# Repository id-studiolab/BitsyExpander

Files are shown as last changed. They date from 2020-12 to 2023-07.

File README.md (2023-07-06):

[][cc-by]

# Bitsy Expander

An expansion board adding support for the Grove solderless connector system, a WiFi radio, and LiPo battery charging circuitry to Adafruit ItsyBitsy Development Boards.

Compatible with all ItsyBitsy boards, the Bitsy Expander is available in two distinct flavors. The silkscreens on each flavor are specifically tailored to either the [ItsyBitsy M4 Express](https://www.adafruit.com/product/3800) or the [ItsyBitsy RP2040](https://www.adafruit.com/product/4888).

**Jump ahead:**

* [Bitsy Expander M4](#bitsy-expander-m4)
* [Bitsy Expander RP2040](#bitsy-expander-rp2040)
* [General Information](#general-information)
* [FAQ](#faq)
* [Version History](#version-history)

## Bitsy Expander M4

### Preview

<p align="center">
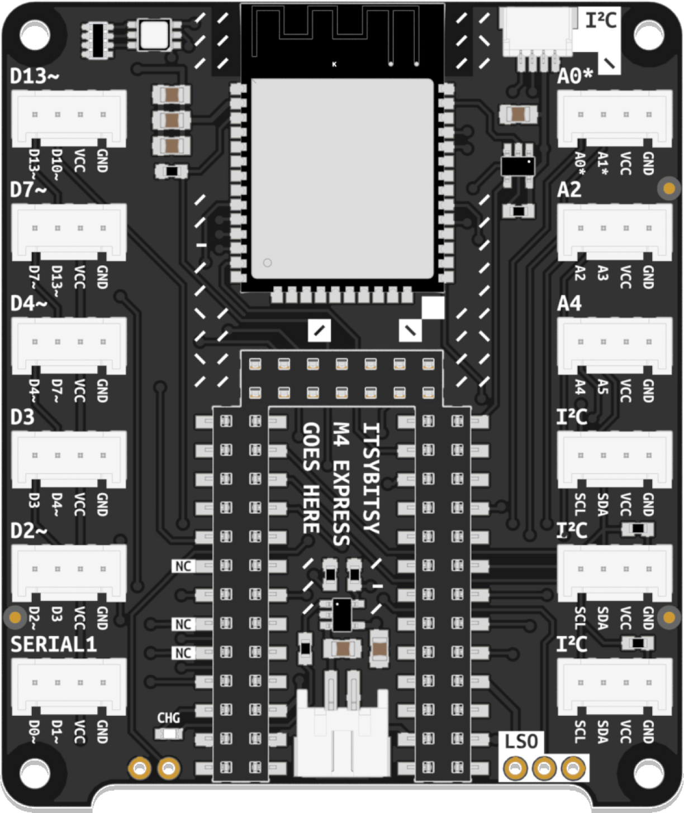
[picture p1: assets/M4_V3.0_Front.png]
Bitsy Expander M4 Front
  
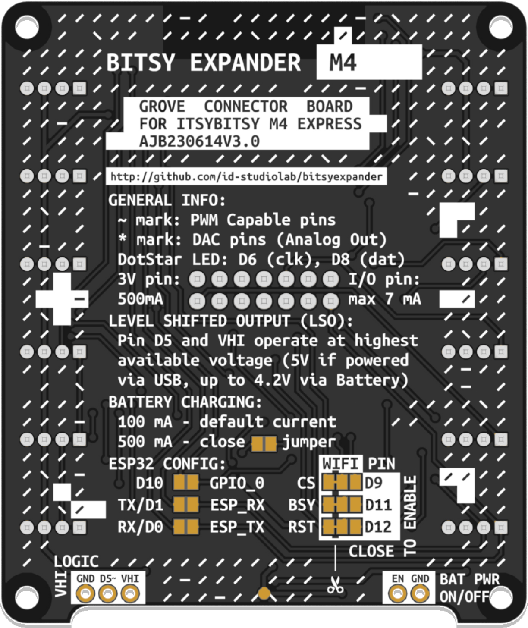
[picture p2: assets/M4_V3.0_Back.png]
Bitsy Expander M4 Back
  
</p>

### Features

* 12 Grove Headers
  - 5 Digital Headers with overlapping (shingled) pins: D2, D3, D4, D7, D13
  - 1 Digital Header with exclusive pins: SERIAL1
  - 3 Analog Headers with exclusive pins: A0, A2, A4
  - 3 I²C Headers
* ESP32-WROOM Co-Processor for WiFi and BLE
* 1 JST SH 4-pin connector for Qwiic and STEMMA QT components (I²C)
* 1 JST PH 2-pin connector for 3.7V LiPo Batteries (chargeable via ItsyBitsy's USB port)
* 1 Logic-shifted output (allows driving components requiring 5V logic while powered via USB)

> NOTE: In shingled pin headers, each header's second pin is shared with the first pin in the header above it. Therefore, using one disables the other. For instance, using pins D3 and D4 in the  D3-labeled header disallows the use of D4 in the D4-labeled header.

### Pinout Diagrams

Additional resources and pinout diagrams are available **[here](M4_info.md)**.

## Bitsy Expander RP2040

### Preview

<p align="center">
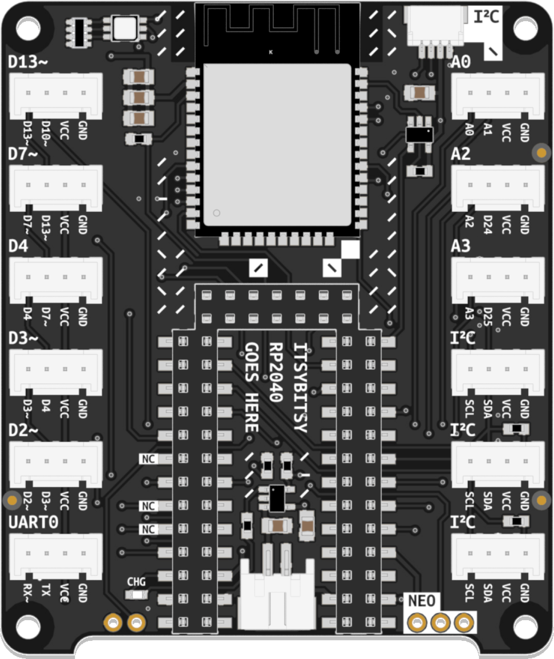
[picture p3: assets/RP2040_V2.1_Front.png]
Bitsy Expander RP2040 Front
  
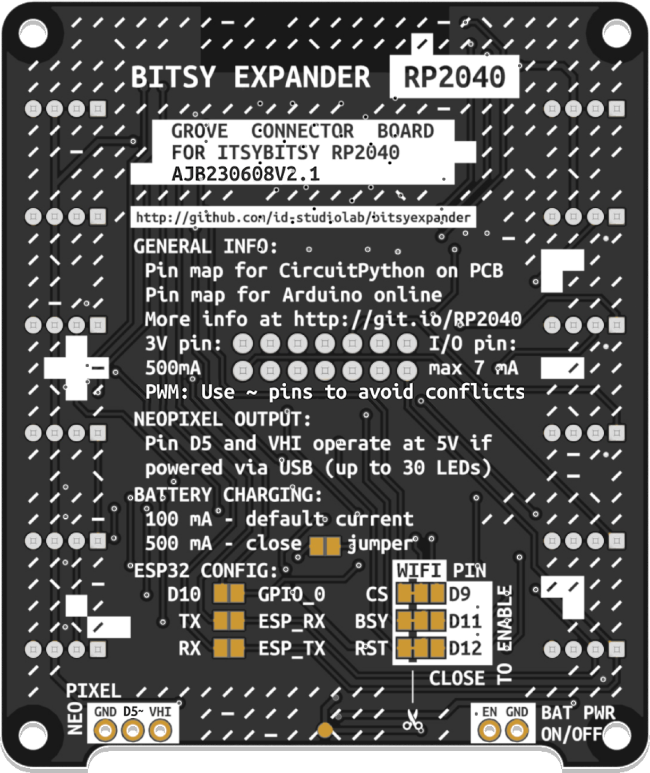
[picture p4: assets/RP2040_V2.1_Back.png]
Bitsy Expander RP2040 Back
  
</p>

### Features

* 12 Grove Headers
  - 5 Digital Headers with overlapping (shingled) pins: D2, D3, D4, D7, D13
  - 1 Digital Header with exclusive pins: UART0
  - 3 Analog Headers with exclusive pins: A0, A2, A3 (A2 and A3 contain digital pins for their second pins)
  - 3 I²C Headers
* ESP32-WROOM Co-Processor for WiFi and BLE
* 1 JST SH 4-pin connector for Qwiic and STEMMA QT components (I²C)
* 1 JST PH 2-pin connector for 3.7V LiPo Batteries (chargeable via ItsyBitsy's USB port)
* 1 Logic-shifted output (allows driving components requiring 5V logic while powered via USB)

> NOTE: In shingled pin headers, each header's second pin is shared with the first pin in the header above it. Therefore, using one disables the other. For instance, using pins D3 and D4 in the  D3-labeled header disallows the use of D4 in the D4-labeled header.

### Pinout Diagrams

Additional resources and pinout diagrams are available **[here](RP2040_info.md)**.

## General Information

### WiFi and BLE

The Bitsy Expander uses an ESP32 WROOM module to provide WiFi functionality to the microcontroller using [Adafruit's fork](https://github.com/adafruit/nina-fw) of the Arduino NINA-W102 firmware. In CircuitPython, this library also allows for the use of Bluetooth Low Energy (BLE).

To use the module with Circuitpython, use the [esp32spi](https://docs.circuitpython.org/projects/esp32spi/en/latest/) library. For Arduino, [Adafruit's forked WiFiNINA](https://github.com/adafruit/WiFiNINA/) library is required.

The ESP32 module is connected as follows:

| ESP32 Pin | ItsyBitsy Pin |
| --- | --- |
| Chip Select (CS) | D9 |
| Busy (BSY) | D11 |
| Reset (RST) | D12 |
| SPI Clock (SCK)  | SCK |
| SPI MISO | MISO |
| SPI MOSI | MOSI |

### Solder Jumpers

The underside of the Bitsy Expander features a number of solder jumpers:

#### WIFI PIN:

These pins are used to connect the ItsyBitsy board to the ESP32 module on the Expander. If WiFi functionality is not needed but additional digital pins are required, these jumpers can be used to disable the WiFi module and make additional pins available in the double-row header on the upper side of the board. The traces between the middle and left pads must be severed before soldering a jumper in place between the middle and the right pads to do so.

#### ESP32 CONFIG:

These solder jumpers are normally open. If the ESP32 module requires a firmware update, these jumpers may be used to enable the ItsyBitsy to serve as a programming interface for the ESP32 module. Refer to [Adafruit's excellent tutorial](https://learn.adafruit.com/upgrading-esp32-firmware) on flashing firmware onto the ESP32.

#### BATTERY CHARGING:

The default battery charging current is 100mA. A faster, 500mA charging mode is available for batteries that support it. It can be enabled by closing the solder jumper.

## FAQ

#### How do I recognize which Bitsy Expander I have?

<p align="center">
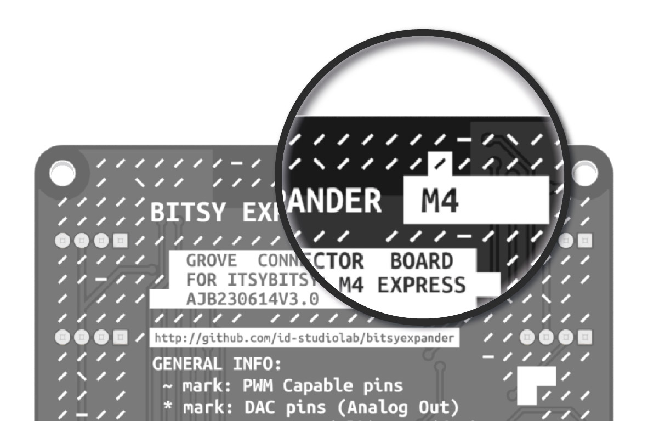
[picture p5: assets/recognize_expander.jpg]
Identify Expander Type
  
</p>

The easiest way to identify which Bitsy Expander flavor you own is checking the label on the back of the board. **RP2040** or **M4** stated on the label indicates the flavor of your Expander. Older M4 Expanders have an **empty label** (and are also recognizable by the lack of an I²C header at the top). 

#### How do I recognize which ItsyBitsy Development Board I am using?

<p align="center" style="display: flex; justify-content: center;">
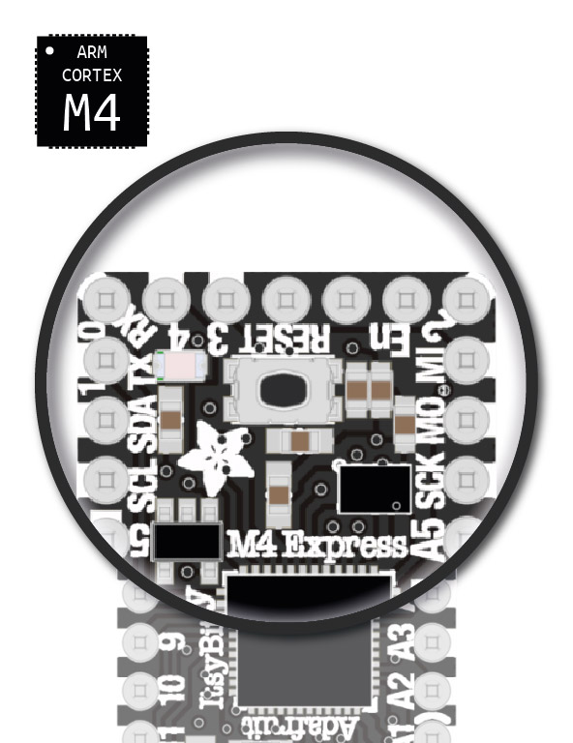
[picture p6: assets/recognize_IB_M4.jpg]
Identify ItsyBitsy M4 Express
  
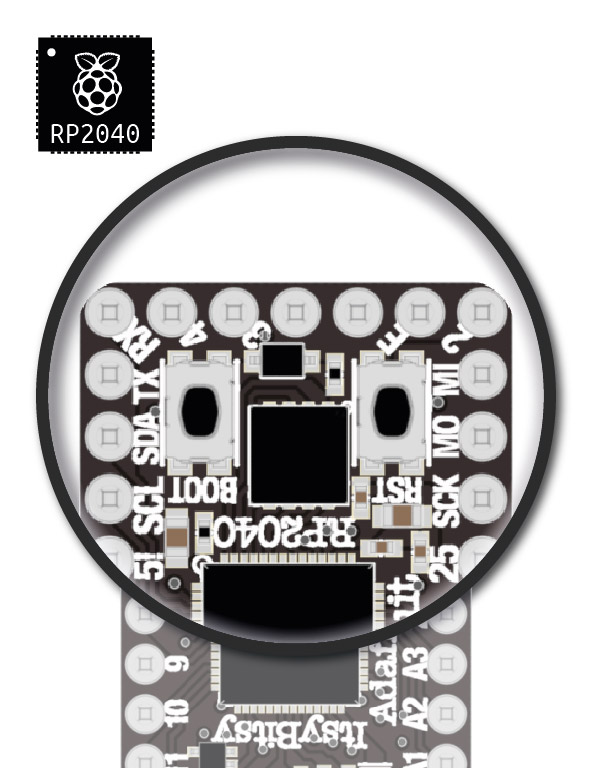
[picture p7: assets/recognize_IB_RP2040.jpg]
Identify ItsyBitsy RP2040
  
</p>

The **ItsyBitsy M4 Express** features **one (RESET) button**. (So do most other ItsyBitsy Development boards, so always verify with the silkscreen.)
The **ItsyBitsy RP2040** features **two (BOOT, RESET) buttons**.

#### Will any ItsyBitsy-type microcontroller work with any Bitsy Expander?

In principle, yes. The silkscreen on either flavor is specifically designed for either the [ItsyBitsy M4 Express](https://www.adafruit.com/product/3800) or the [ItsyBitsy RP2040](https://www.adafruit.com/product/4888), respectively. Pinouts differ only slightly between ItsyBitsy Development boards, however. The M4 Expander, for instance, has also been used successfully with the [ItsyBitsy M0 Express](https://www.adafruit.com/product/3727) in the past. This repository includes a number of pinout diagrams for different use-cases.

## Version History

| Version | Comment | Known Issues | Flavors |
| --- | --- | --- | --- |
| **1.0** | Initial version | Using pin D13 to drive the ESP Chip Select (CS) causes interference between the microcontroller's internal LED and the pull-up resistor | M4 Express |
| 1.1 | – Uses pin D9 instead of D13 to drive the ESP Chip Select to prevent interference  <br />– Adds a test point to the expander's underside for VBAT accessibility | Only two Grove headers provide direct access to Analog pins of used with RP2040 | M4 Express, RP2040 |
| **2.0** | – Adds a top-edge JST SH 4-pin connector for Qwiic and STEMMA QT compatibility  <br />– Repositions pin A3 for better RP2040 analog pin access<br />– Adds "NC" (not connected) labels to double-row header pins that are not normally broken out | Tilde (~) marks inaccurately represent freely configurable PWM pins on RP2040. *Note: all pins support PWM, subject to certain limitations.* | RP2040 |
| 2.1 | Silkscreen update to accurately depict a selection of freely configurable PWM pins on RP2040, preventing configuration conflicts among them | | RP2040 |
| **3.0** | – Reinstates original pin layout (identical to V1) for sequential analog pin placement on M4 Express <br />– Maintains JST SH-4 connector and VBAT test point inherited from previous versions | | M4 Express |

This is the sibling of the [Nano Expander](https://github.com/id-studiolab/NanoExpander), a Grove expansion board for [Arduino Nano 33 IoT](https://store.arduino.cc/products/arduino-nano-33-iot).

This work is licensed under a
[Creative Commons Attribution 4.0 International License][cc-by].

[][cc-by]

[cc-by]: http://creativecommons.org/licenses/by/4.0/
[cc-by-image]: https://i.creativecommons.org/l/by/4.0/88x31.png
[cc-by-shield]: https://img.shields.io/badge/License-CC%20BY%204.0-lightgrey.svg

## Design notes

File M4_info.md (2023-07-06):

# Bitsy Expander M4 Pinout Diagrams
The ItsyBitsy M4 Express is a powerful and versatile development board powered by a 32-bit Cortex M4 microcontroller running at 120 MHz. It features two 12-bit DACs, seven 12-bit ADCs, and plenty PWM-capable outputs. 

This page provides an overview of the pins made available via the Grove headers on the Bitsy Expander M4.

**For detailed information on the pinout of the ItsyBitsy M4 Express, refer to Adafruit's documentation:**  

[Adafruit ItsyBitsy M4 Express](https://learn.adafruit.com/introducing-adafruit-itsybitsy-m4)

**Jump ahead to pinout diagram:**

* [Pinout for Standard Usage](#standard-usage)
* [Original Bitsy Expander (Version 1.1)](#original-bitsy-expander-version-11)
* [Alternative Use with ItsyBitsy RP2040](#alternative-use-with-itsybitsy-rp2040)

## Standard Usage

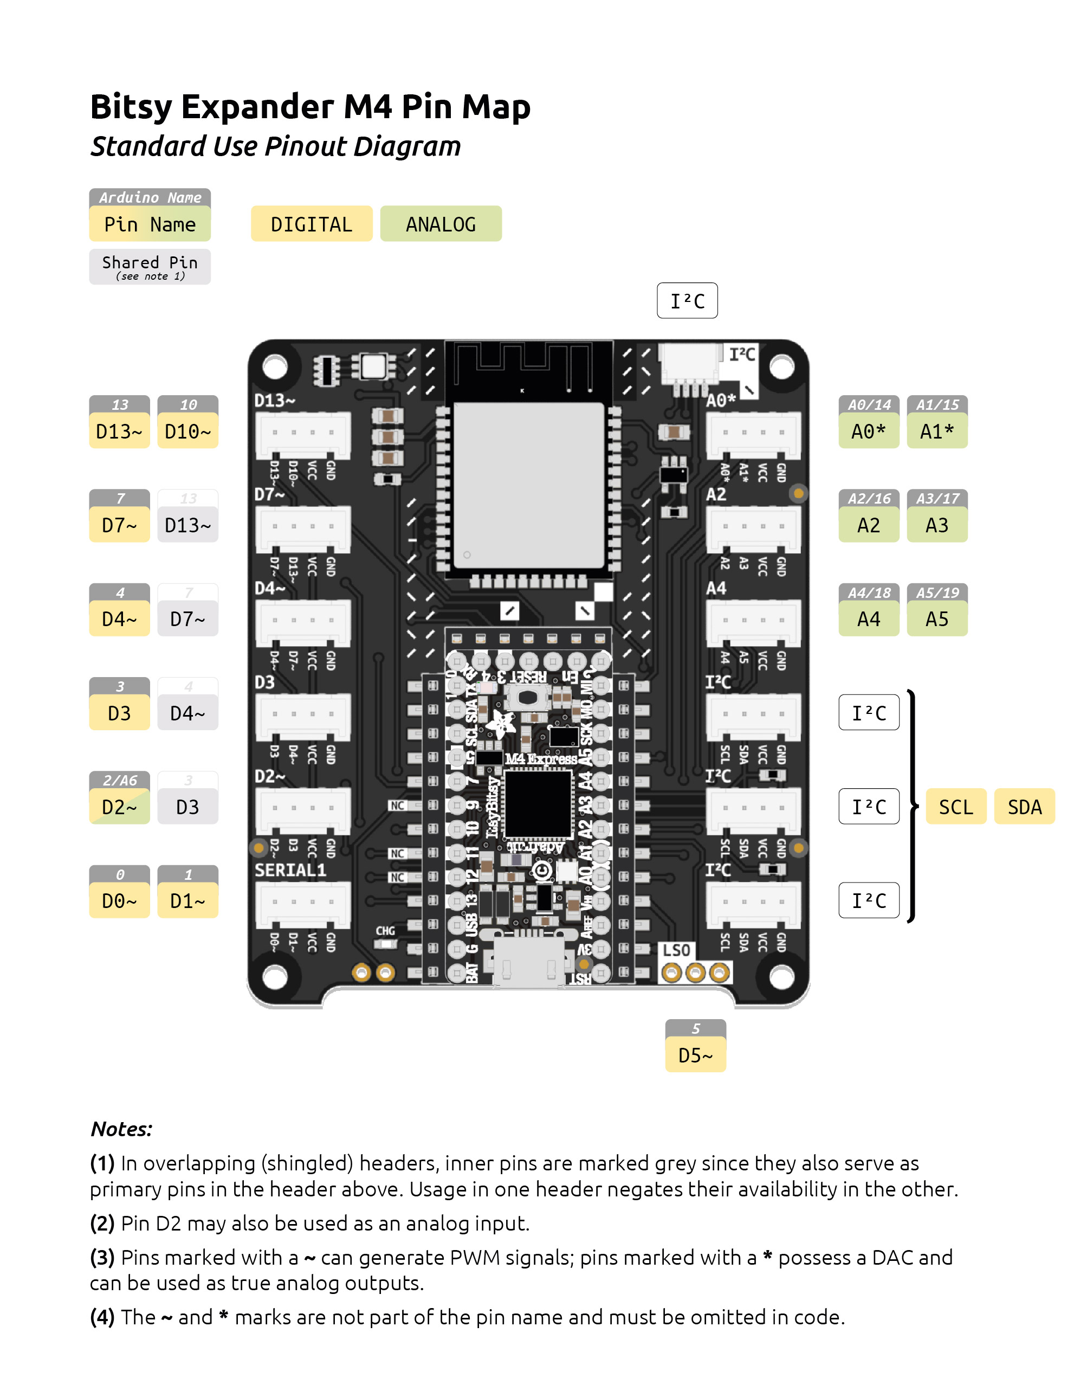
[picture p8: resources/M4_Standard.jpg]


## Original Bitsy Expander (Version 1.1)
The pinout of this version is identical to the version pictured above. The only major difference is the absence of the additional I²C header at the top of the board. This diagram serves as a visual reference for older boards still in circulation.

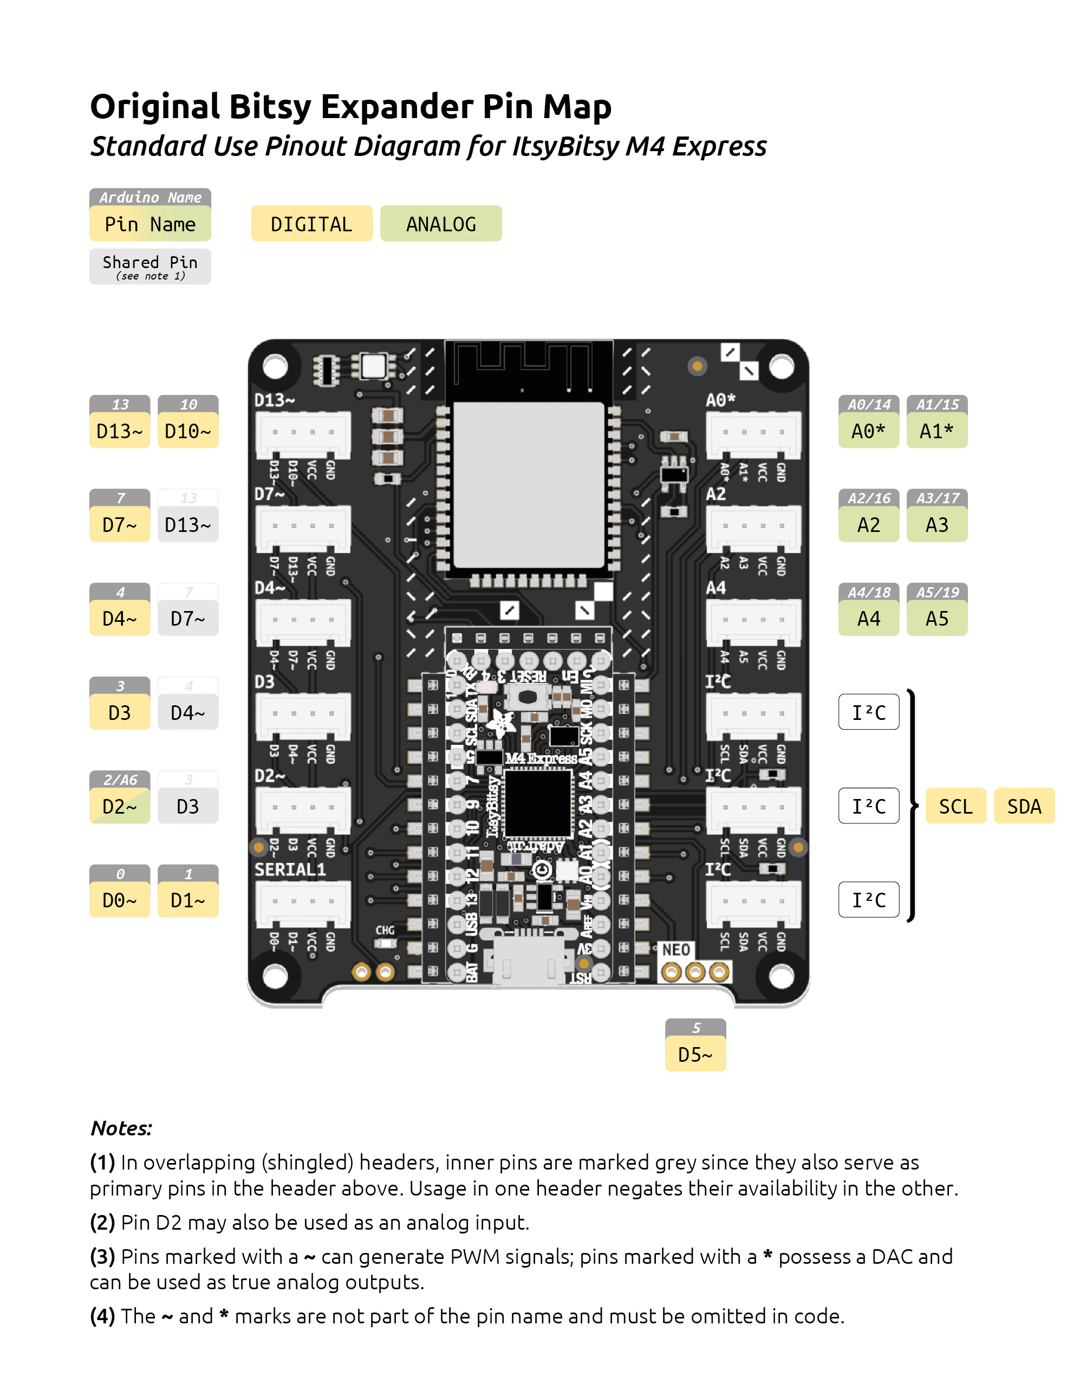
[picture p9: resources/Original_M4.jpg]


## Alternative Use with ItsyBitsy RP2040

Should you opt to use a Bitsy Expander M4 with an ItsyBitsy RP2040 development board, please refer to the pinout diagram below:

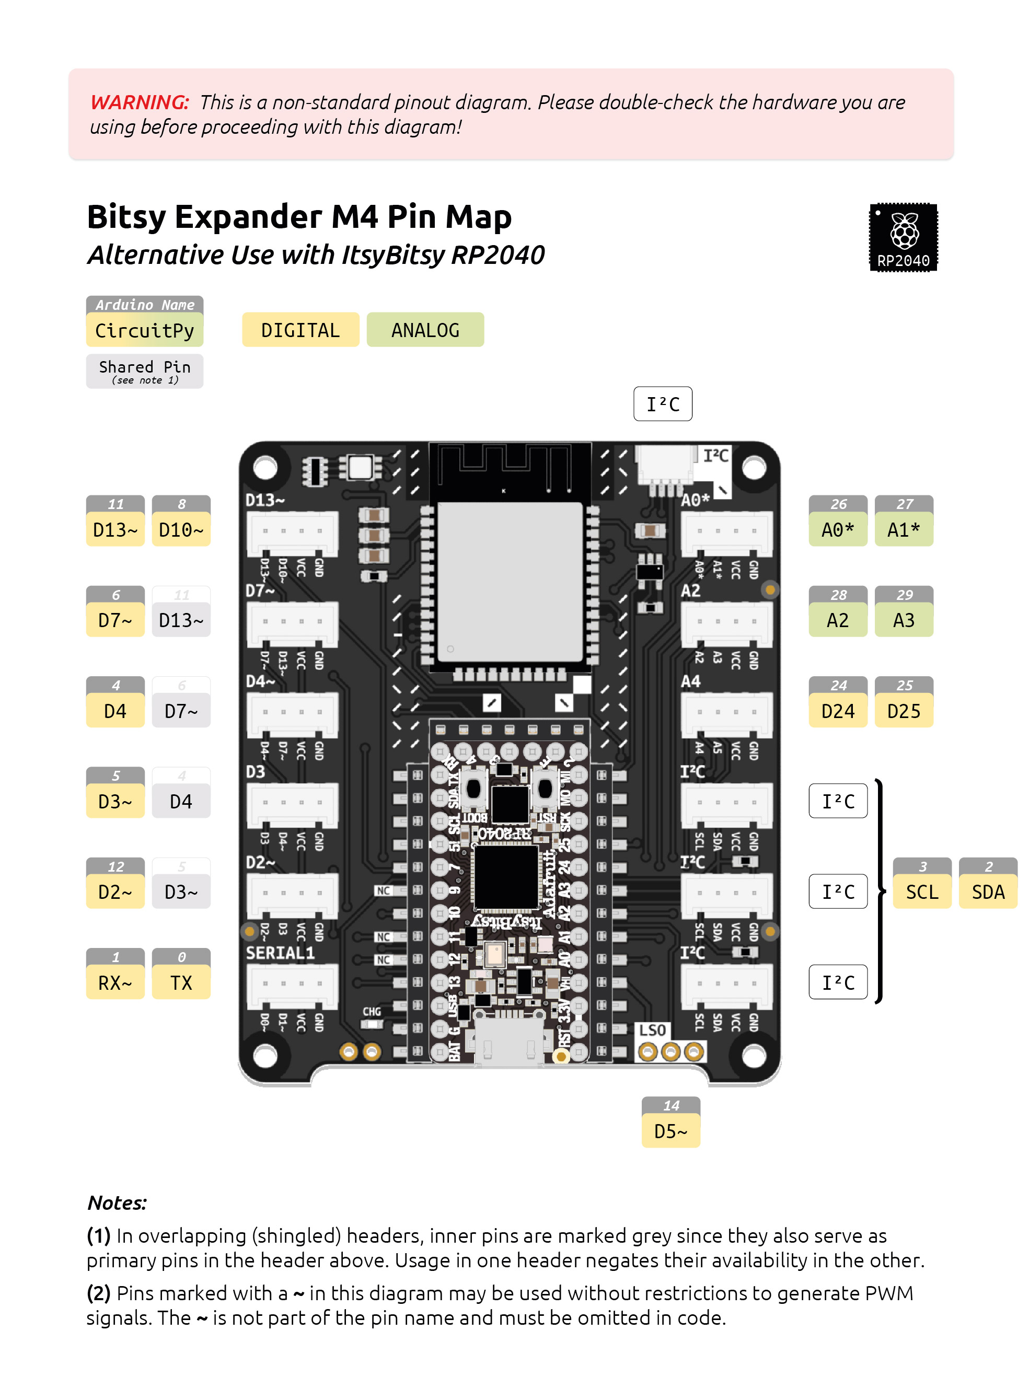
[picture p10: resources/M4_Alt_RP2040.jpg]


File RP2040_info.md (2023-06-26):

# Bitsy Expander RP2040 Pinout Diagrams
Unlike the ItsyBitsy M4, which includes two more analog pins (and two DACs), the RP2040 replaces these with two additional digital pins. The RP2040 affords greater flexibility in GPIO pin usage, but extra planning and research may be needed to fully leverage this advantage.

**For detailed information on the ItsyBitsy RP2040's pinout, refer to Adafruit's documentation:**  

[Adafruit ItsyBitsy RP2040](https://learn.adafruit.com/adafruit-itsybitsy-rp2040)

**Jump ahead to pinout diagram:**

* [Pinout for Standard Usage](#standard-usage)
* [Advanced PWM and PIO Reference](#advanced-pwm-and-pio-reference)
* [Pinout for use in Arduino IDE](#arduino-support)
* [Alternative Use with ItsyBitsy M4 Express](#alternative-use-with-itsybitsy-m4-express)

## Standard Usage

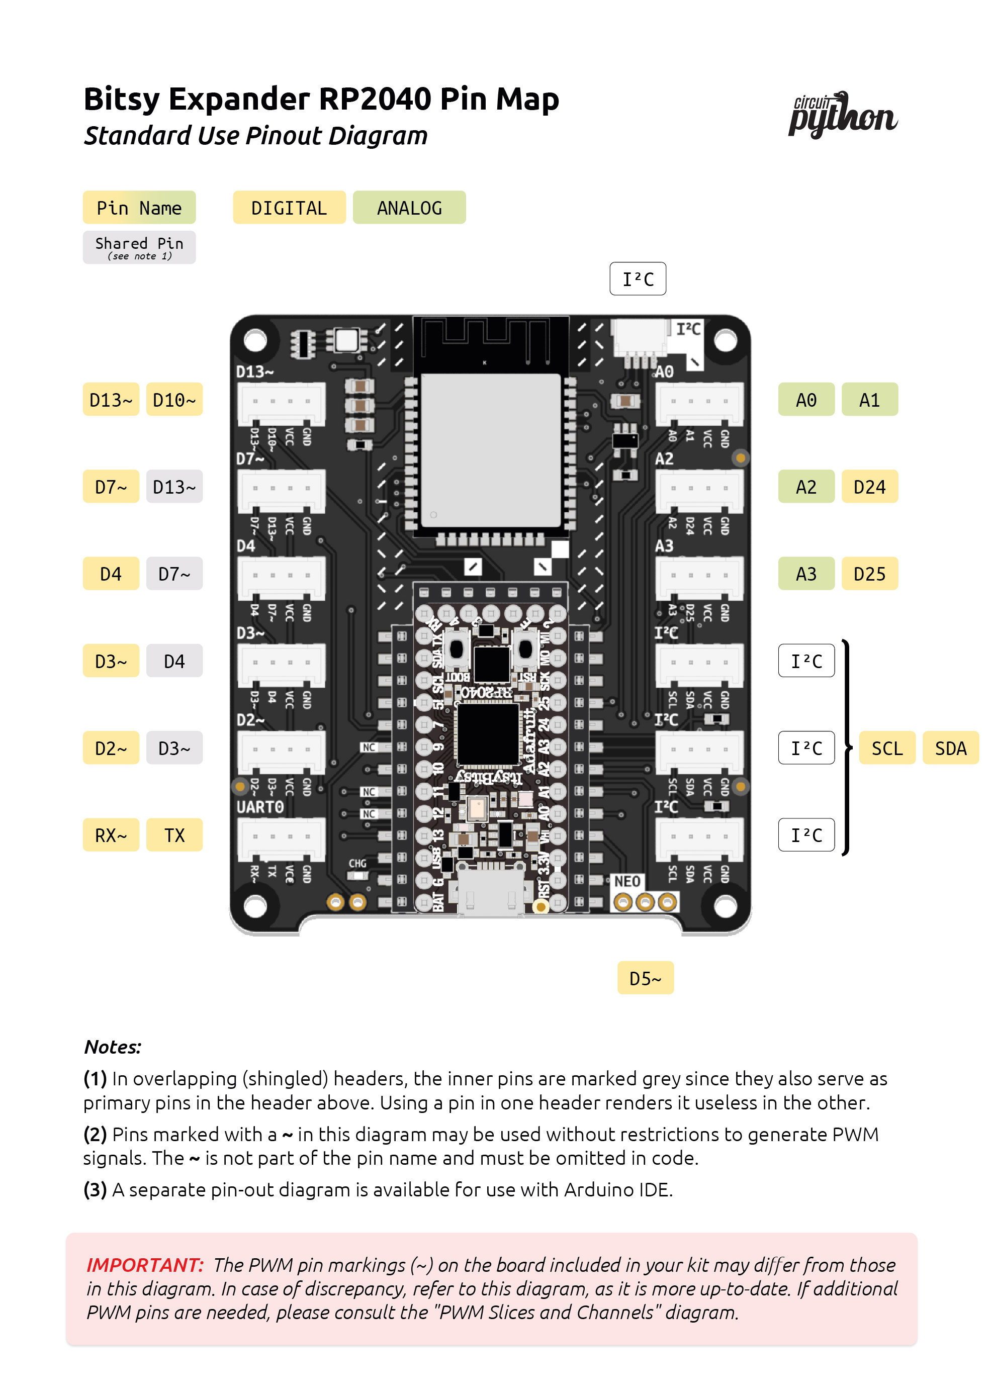
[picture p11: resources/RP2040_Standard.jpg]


## Advanced PWM and PIO Reference
The RP2040 is a highly capable microcontroller that features flexible hardware support for Pulse Width Modulation (PWM) and Programmable I/O (PIO). With 8 available PWM slices, each offering 2 channels, and 2 PIO  blocks with 4 state machines each, developers can control a variety of digital peripherals and create custom digital interfaces.

However, this versatility necessitates careful planning. While every IO can generate PWM signals, restrictions apply to the simultaneous use of specific pins. (e.g., pins sharing a common PWM slice must adopt identical frequency settings.) These constraints allow simultaneous PWM use of all pins for many standard use-cases. For scenarios requiring custom settings, the silkscreen displays marks (~) for a group of pins that can be freely configured without causing conflicts. For more advanced needs, the diagram below serves as a reference. Please refer to Note 3 in the diagram for more information.

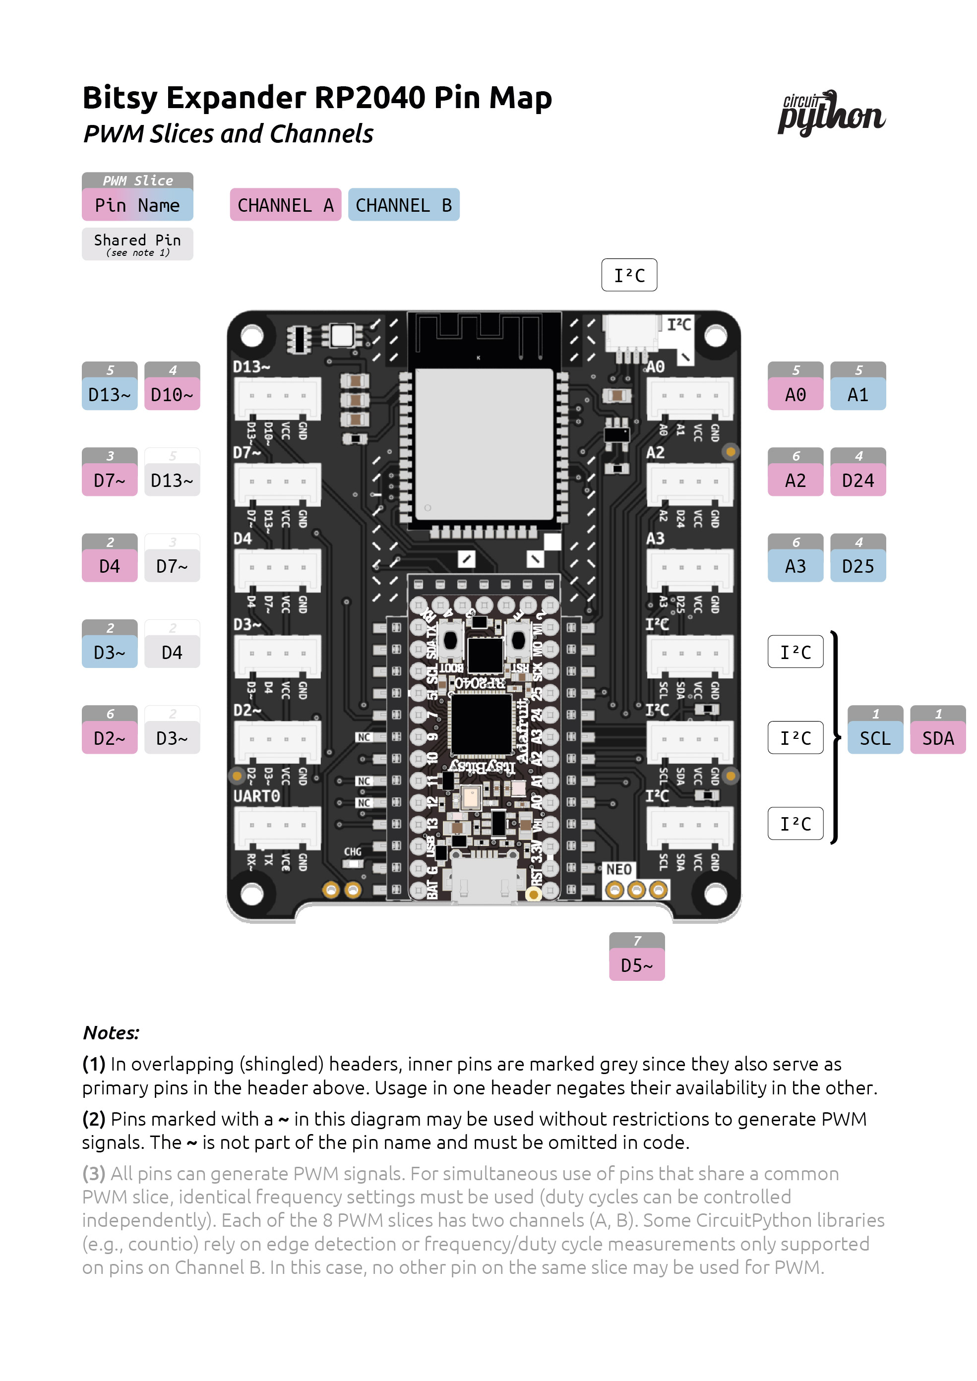
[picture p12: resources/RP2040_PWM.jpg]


## Arduino Support
The pin markings on both the BitsyExpander RP2040 and the ItsyBitsy RP2040 itself are exclusively applicable for use with [CircuitPython](https://circuitpython.org/board/adafruit_itsybitsy_rp2040/). To program the board using [Arduino](https://learn.adafruit.com/adafruit-itsybitsy-rp2040/arduino-ide-setup), use the pin map provided here.

**Relevant links:**  
[Arduino IDE set-up for ItsyBitsy RP2040](https://learn.adafruit.com/adafruit-itsybitsy-rp2040/arduino-ide-setup)  
[Earlephilhower's Pi Pico Arduino Core](https://github.com/earlephilhower/arduino-pico/#arduino-pico)  

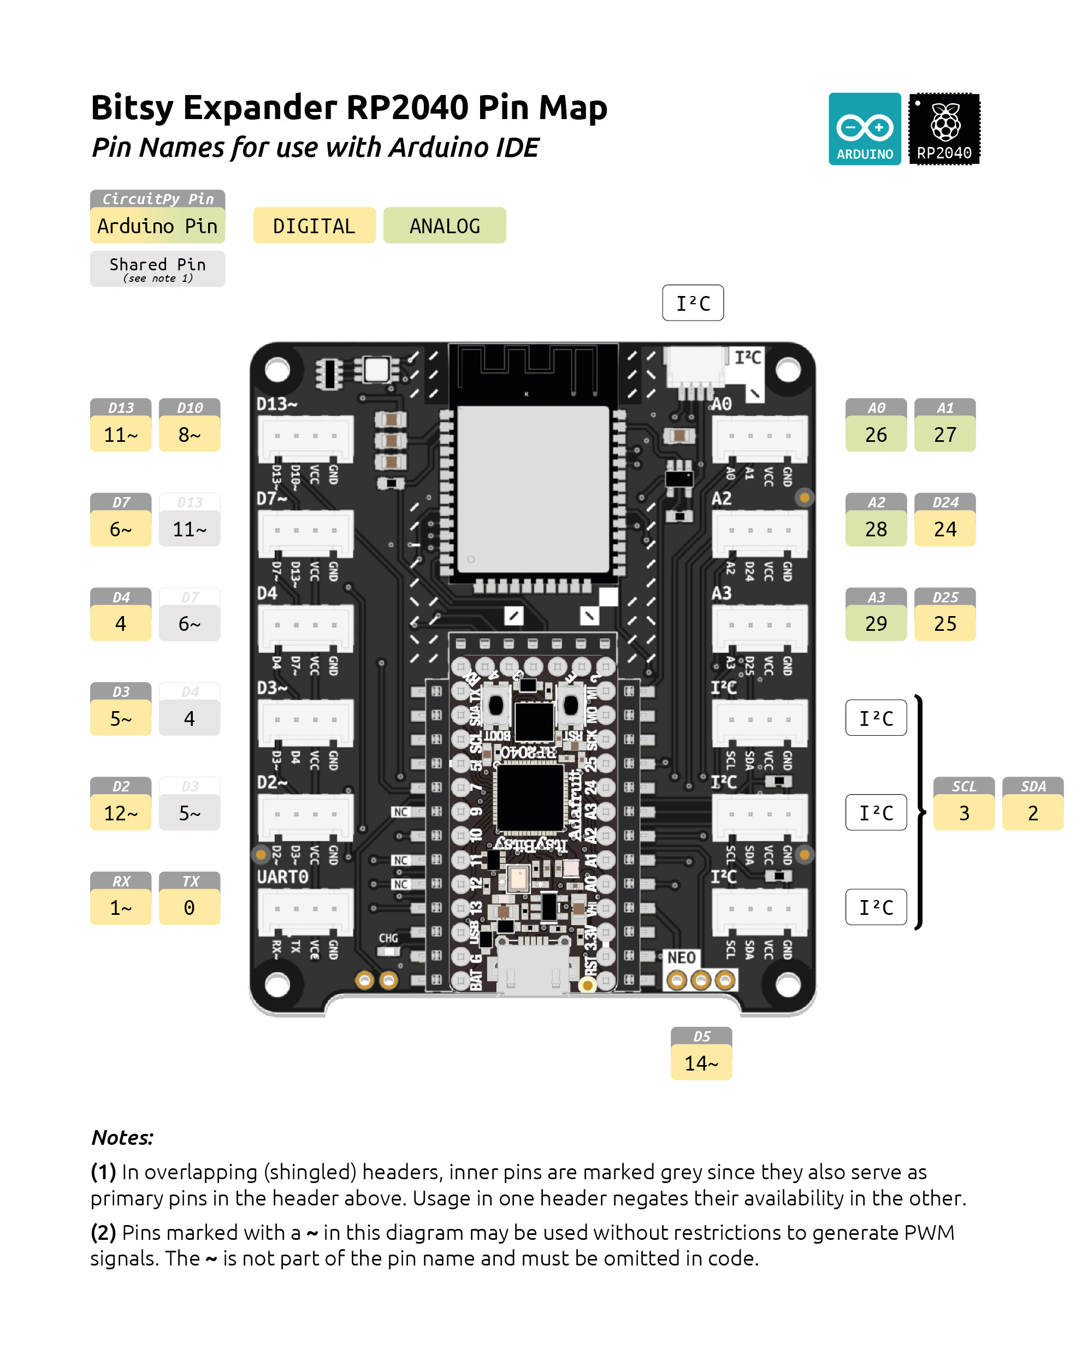
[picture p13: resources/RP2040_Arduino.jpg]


## Alternative Use with ItsyBitsy M4 Express

Should you opt to use a Bitsy Expander RP2040 with an ItsyBitsy M4 Express development board, please refer to the pinout diagram below:

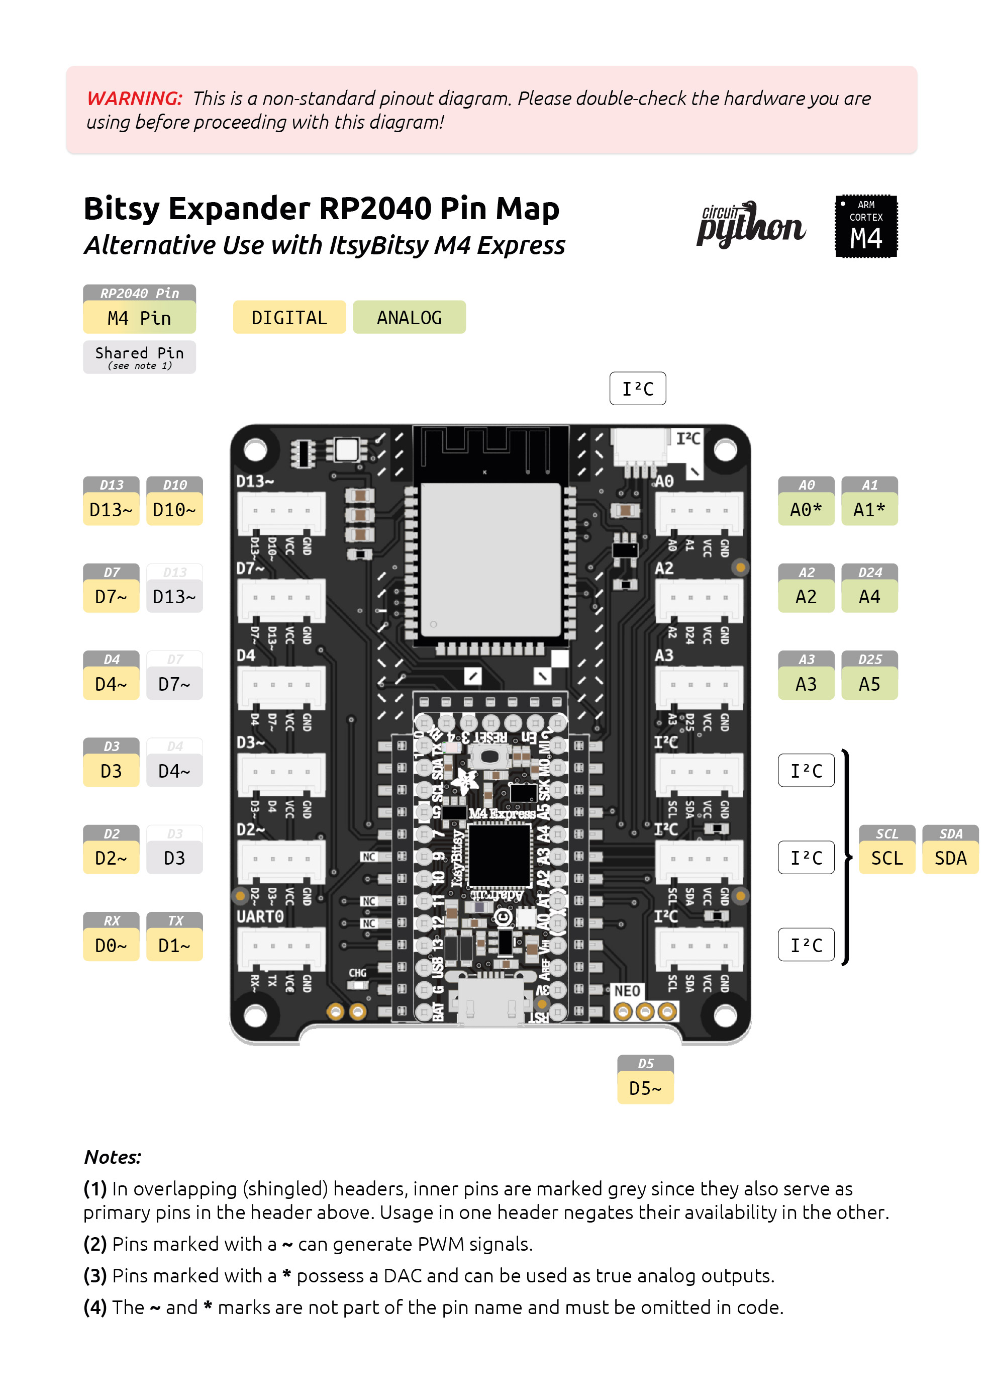
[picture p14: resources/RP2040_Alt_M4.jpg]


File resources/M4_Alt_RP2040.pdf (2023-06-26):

## Alternative Use with ItsyBitsy RP2040

## Bitsy Expander M4 Pin Map

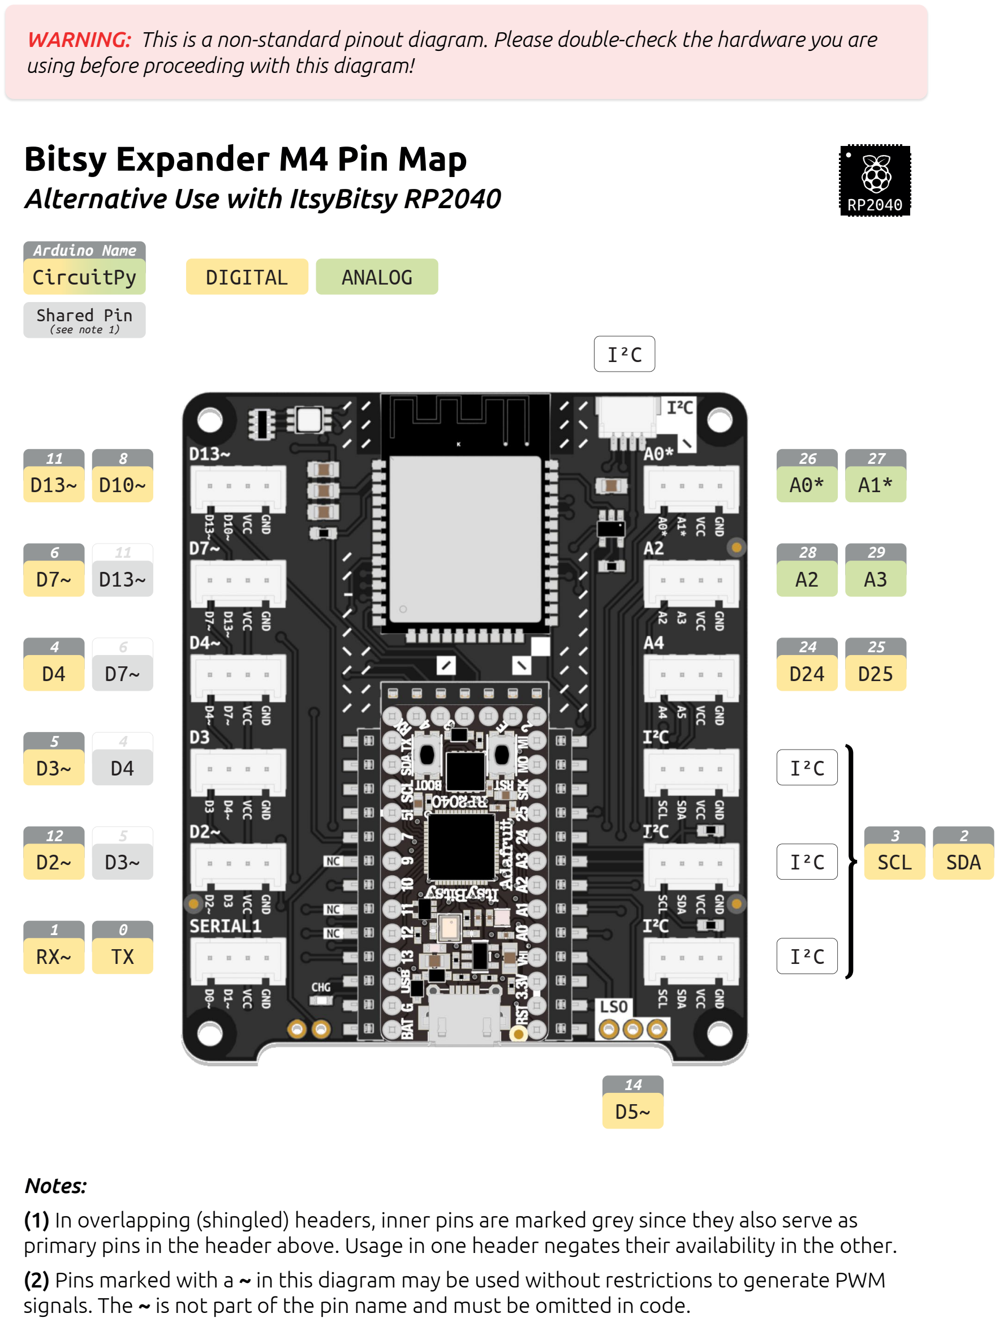
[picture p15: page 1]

D10~

8
D13~

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
D13~

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
I²C | SDA
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
RP2040

CircuitPy | DIGITAL | ANALOG

Arduino Name

Notes:
(1) In overlapping (shingled) headers, inner pins are marked grey since they also serve as primary pins in the header above. Usage in one header negates their availability in the other.
(2) Pins marked with a ~ in this diagram may be used without restrictions to generate PWM signals. The ~ is not part of the pin name and must be omitted in code.

WARNING: This is a non-standard pinout diagram. Please double-check the hardware you are using before proceeding with this diagram!

I²C

Shared Pin
(see note 1)

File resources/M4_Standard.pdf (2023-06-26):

## Bitsy Expander M4 Pin Map

## Standard Use Pinout Diagram

I²C

I²C | SCL | SDA

I²C

D10~

10
D13~

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
2⁄A6

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
D13~

13
D7~

7

A1*

A1⁄15
A0*

A0⁄14

A5

A5⁄19
A4

A4⁄18

A3

A3⁄17
A2

A2⁄16

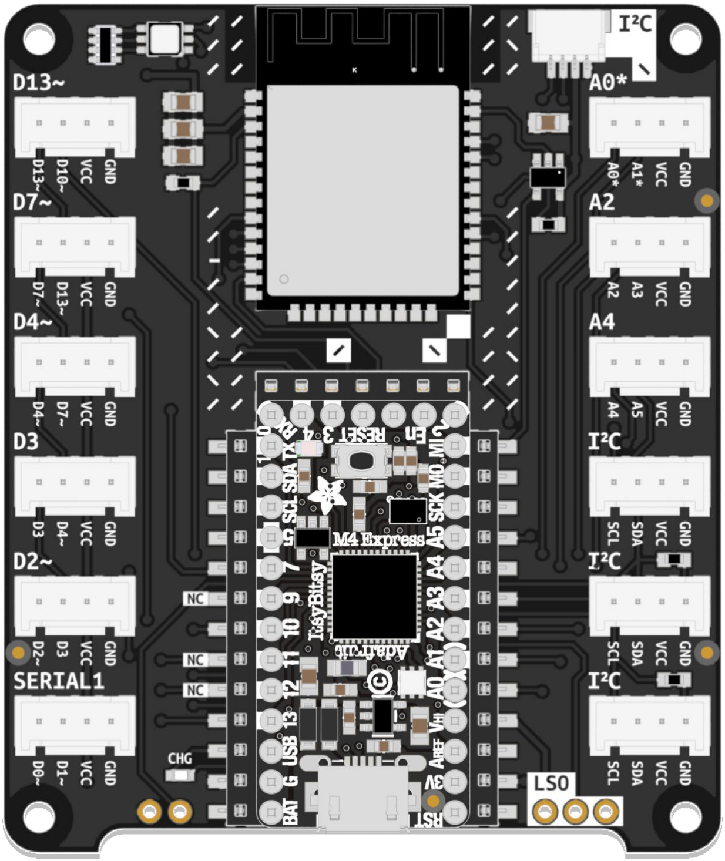
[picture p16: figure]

D5~

5

Pin Name

Arduino Name
DIGITAL ANALOG

Notes:
(1) In overlapping (shingled) headers, inner pins are marked grey since they also serve as primary pins in the header above. Usage in one header negates their availability in the other.
(2) Pin D2 may also be used as an analog input.
(3) Pins marked with a ~ can generate PWM signals; pins marked with a * possess a DAC and can be used as true analog outputs.
(4) The ~ and * marks are not part of the pin name and must be omitted in code.

I²C

Shared Pin
(see note 1)

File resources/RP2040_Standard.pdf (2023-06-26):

D13~ D10~

RX~ | TX
D2~ | D3~
D3~ | D4
D4 | D7~

D7~ D13~

A0 A1

I²C

I²C | SCL | SDA

I²C

I²C

A3 | D25
A2 | D24

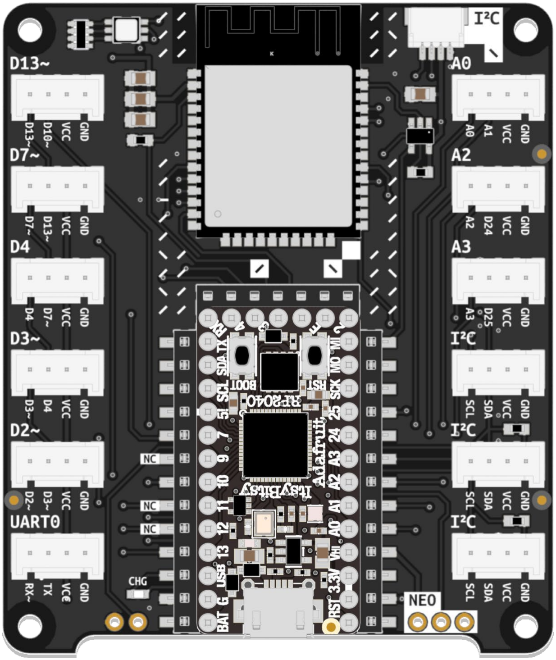
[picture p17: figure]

D5~

## Bitsy Expander RP2040 Pin Map

## Standard Use Pinout Diagram

Pin Name | DIGITAL | ANALOG

Notes:
(1) In overlapping (shingled) headers, the inner pins are marked grey since they also serve as primary pins in the header above. Using a pin in one header renders it useless in the other.
(2) Pins marked with a ~ in this diagram may be used without restrictions to generate PWM signals. The ~ is not part of the pin name and must be omitted in code.
(3) A separate pin-out diagram is available for use with Arduino IDE.

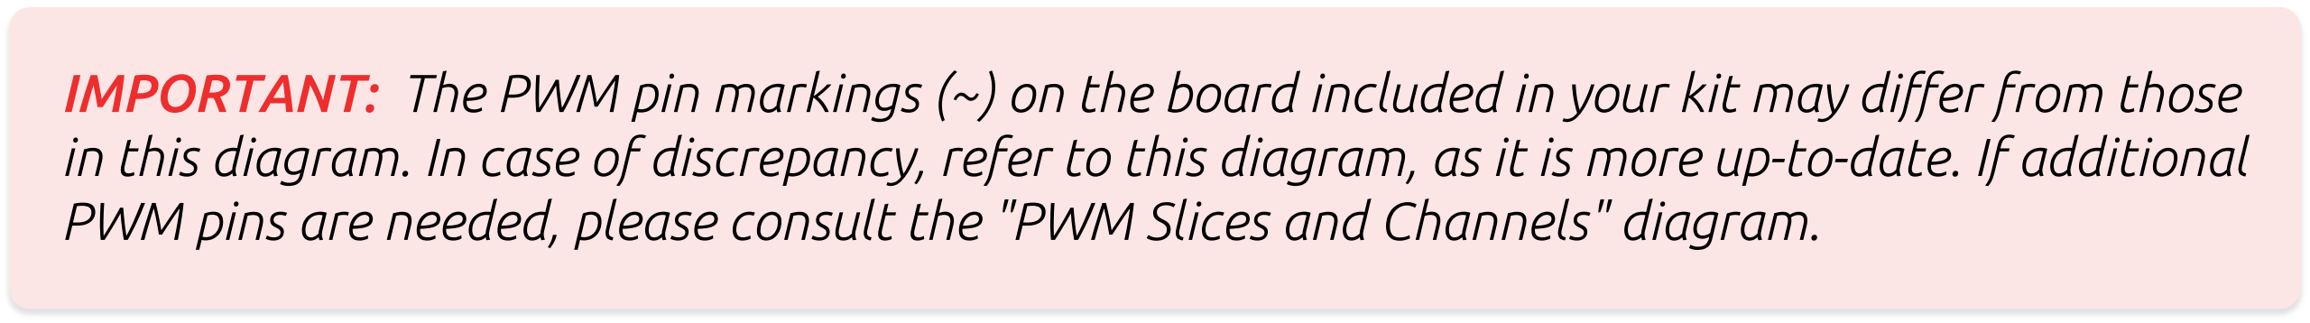
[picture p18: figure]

IMPORTANT: The PWM pin markings (~) on the board included in your kit may differ from those in this diagram. In case of discrepancy, refer to this diagram, as it is more up-to-date. If additional PWM pins are needed, please consult the "PWM Slices and Channels" diagram.

Shared Pin
(see note 1)

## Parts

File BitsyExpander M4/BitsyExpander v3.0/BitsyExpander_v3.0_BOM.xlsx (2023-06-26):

Designator | Manufacturer Part Number or Seeed SKU | Supplier | Qty | Value | Package | Link | Data sheet | Remarks
C1,C2,C3,C4,C5 | 302010158 | Seeed OPL | 5 | 10 µF | C0805 | https://statics3.seeedstudio.com/fusion/opl/datasheet/302010158.pdf
C6 | 302010165 | Seeed OPL | 1 | 0.1 µF | C0805 | https://statics3.seeedstudio.com/fusion/opl/datasheet/302010165.pdf
CON1 | SM04B-SRSS-TB(LF)(SN) | LCSC | 1 | 1x4 Pin | JST SH 4 Pin | https://lcsc.com/product-detail/Wire-To-Board-Wire-To-Wire-Connector_JST-Sales-America-SM04B-SRSS-TB-LF-SN_C160404.html | https://datasheet.lcsc.com/lcsc/1811151533_JST-Sales-America-SM04B-SRSS-TB-LF-SN_C160404.pdf | If possible to source, use black version: https://www.adafruit.com/product/4208
CON2 | S2B-PH-SM4-TB(LF)(SN) | LCSC | 1 | 1x2 Pin | JST PH 2 Pin | https://lcsc.com/product-detail/Wire-To-Board-Wire-To-Wire-Connector_JST-Sales-America-S2B-PH-SM4-TB-LF-SN_C295747.html | https://datasheet.lcsc.com/lcsc/2102031704_JST-Sales-America-S2B-PH-SM4-TB-LF-SN_C295747.pdf | If possible to source, use black version: https://www.adafruit.com/product/1769
CON3, CON4, CON5, CON6, CON7, CON8, CON9, CON10, CON11, CON12, CON13, CON14 | 320110033 | Seeed OPL | 12 | Seeed Grove Female Header | 4 Pin SMD | https://statics3.seeedstudio.com/fusion/opl/datasheet/320110033.pdf
CON15 | A2541HWV-2X7P | ShenZen OPL | 1 | 2x7 Pin | 2.54mm Pitch | https://file.elecfans.com/web1/M00/81/AC/o4YBAFw2vnKAaVFEACnRtF3lcuA967.pdf?filename=A2541_SERIES_CJT.pdf | https://www.cjt.com/Upload/A2541.pdf | 2.54mm Pitch 180° Female PTH 2x7 Pin Dual Row Header
CON16, CON17 | A2541HWV-S-2x13P | AliExpress | 2 | 2x13 Pin | 2.54mm Pitch | https://www.aliexpress.com/item/32798959899.html | https://www.cjt.com/Upload/A2541.pdf | 2.54mm Pitch 180° Female SMD 2x13 Pin Dual Row Header
LED1 | 304090042 | Seeed OPL | 1 | RED | 0603 | https://statics3.seeedstudio.com/fusion/opl/datasheet/304090042.pdf
LED2 | ASMT-YTD7-0AA02 | LCSC | 1 | ASMT-YTD7-0AA02 | 3528 | https://lcsc.com/product-detail/Light-Emitting-Diodes-LED_Broadcom-Limited-ASMT-YTD7-0AA02_C3018557.html | https://datasheet.lcsc.com/lcsc/2206171715_Broadcom-Limited-ASMT-YTD7-0AA02_C3018557.pdf
R1 | 301010298 | Seeed OPL | 1 | 1k | R0603 | https://statics3.seeedstudio.com/fusion/opl/datasheet/301010298.pdf
R2, R4, R5, R6, R7 | 301010299 | Seeed OPL | 5 | 10k | R0603 | https://statics3.seeedstudio.com/fusion/opl/datasheet/301010299.pdf
R3 | 0603WAF8252T5E | ShenZen OPL | 1 | 2.5k | R0603 | https://file.elecfans.com/web1/M00/8F/24/o4YBAFy-fqCABd01AAciZeje3jQ155.pdf
RN1 | WA06X222JTL | LCSC | 1 | 2.2K 4 Resistor Array | 4D03 | https://lcsc.com/product-detail/Resistor-Networks-Arrays_Walsin-Tech-Corp-WA06X222JTL_C168190.html
U1 | ESP32-WROOM-32E(8MB) | ShenZen OPL | 1 | ESP-WROOM-32 | ESP-WROOM-32 |  | https://www.espressif.com/sites/default/files/documentation/esp32-wroom-32e_esp32-wroom-32ue_datasheet_en.pdf
U2 | SN74AHC1G125DBVR | ShenZen OPL | 1 | 74AHC1G125 | SOT23-5L | https://file.elecfans.com/web1/M00/9F/43/pIYBAF1AqlCAeSb7ABGz_e2uUbE107.pdf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 | https://www.ti.com/lit/ds/symlink/sn74ahc1g125.pdf
U3 | MCP73831T-2ACI/OT | ShenZen OPL | 1 | MCP73831 | SOT23-5 | https://file.elecfans.com/web1/M00/9F/3E/pIYBAF1AlmqAaVGPAAzcNzr-I_c971.pdf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 | https://ww1.microchip.com/downloads/en/DeviceDoc/20001984g.pdf

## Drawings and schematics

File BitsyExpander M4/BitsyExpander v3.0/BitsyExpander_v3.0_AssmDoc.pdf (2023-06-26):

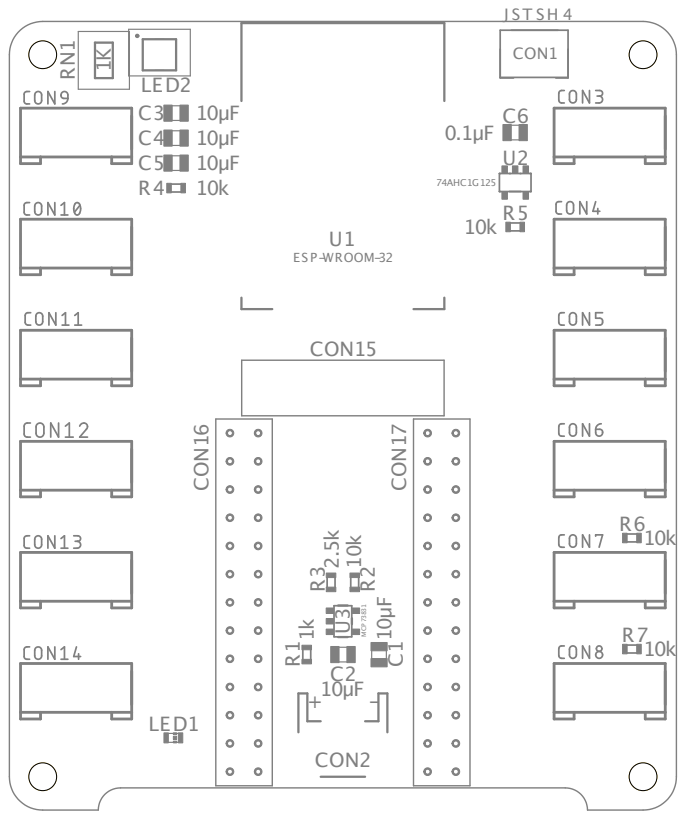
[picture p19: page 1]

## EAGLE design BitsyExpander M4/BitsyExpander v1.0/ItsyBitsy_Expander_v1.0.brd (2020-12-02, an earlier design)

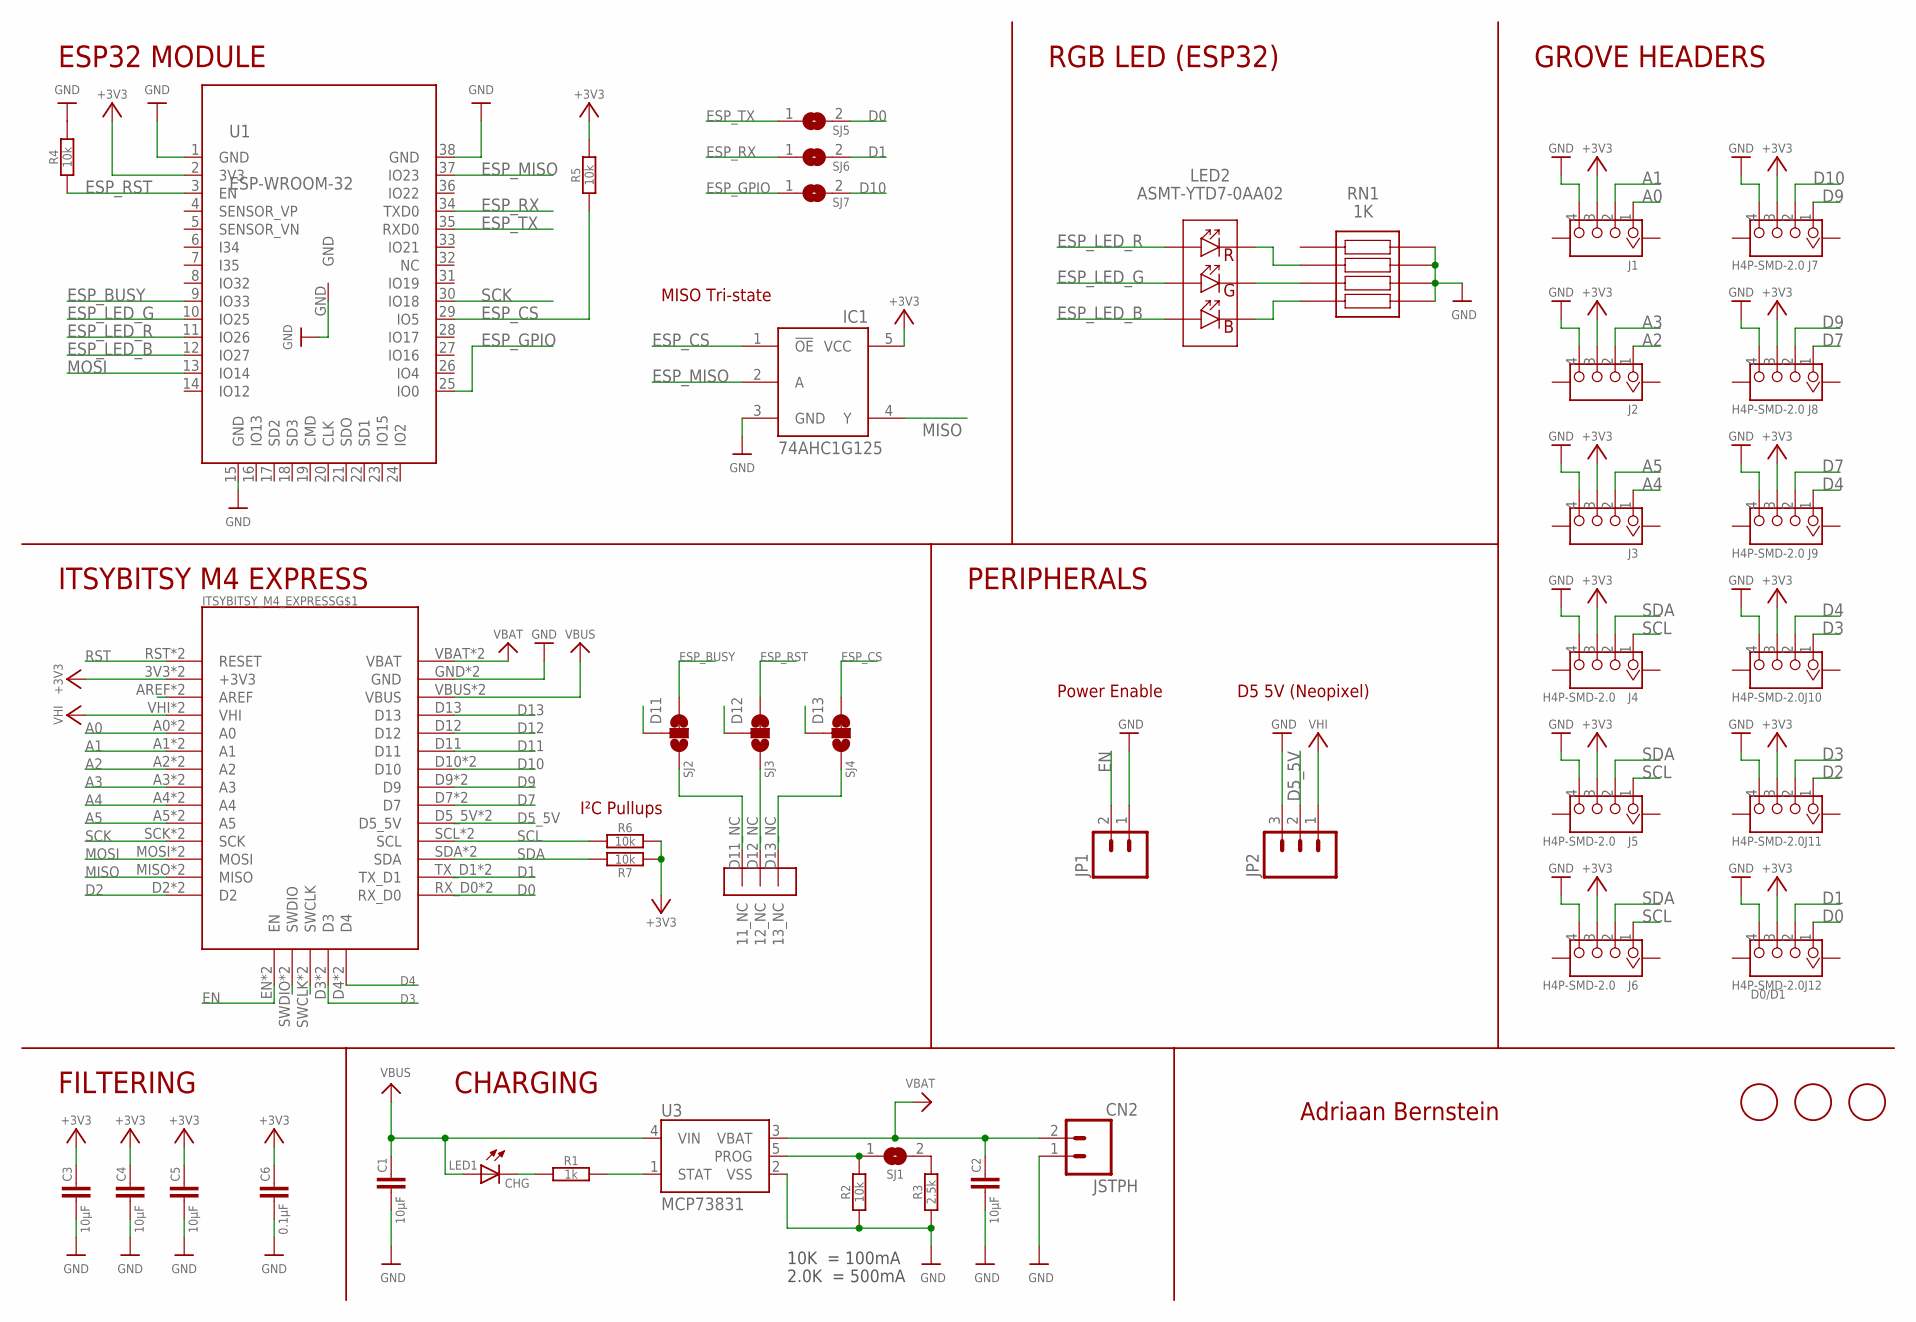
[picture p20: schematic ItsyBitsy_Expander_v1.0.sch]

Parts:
C1, C2, C3, C4, C5: 10µF; C0805
C6: 0.1µF; C0603
CN2: JSTPH; JST-2-SMD
IC1: 74AHC1G125; SOT23-5L
ITSYBITSY_M4_EXPRESS: ITSYBITSY_M4_NC; ITSYBITSY_M4_MIXED_DOUBLEHEADERS_ALL_NC
J1, J2, J3, J4, J5, J6, J7, J8, J9, J10, J11, J12: H4P-SMD-2.0; HW4-SMD-2.0
JP1: M02PTH; 1X02
JP2: M03PTH; 1X03
LED1: CHG; CHIP-LED0603
LED2: ASMT-YTD7-0AA02; ASMTYTD70AA02
R1: 1k; R0603
R2, R4, R5, R6, R7: 10k; R0603
R3: 2.5k; R0603
RN1: 1K; CAY1647R0F4LF
SJ1, SJ5, SJ6, SJ7: SJ
SJ_D11: SJ2; SJ_2WAY_CLOSED
SJ_D12: SJ3; SJ_2WAY_CLOSED
SJ_D13: SJ4; SJ_2WAY_CLOSED
U1: ESP-WROOM-32
U3: MCP73831; SOT23-5
U$23, U$35, U$36: FIDUCIAL; FIDUCIAL_1MM

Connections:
2.5K: R3.2, SJ1.2
10K: R2.2, SJ1.1, U3.5 (PROG)
+3V3: C3.1, C4.1, C5.1, C6.1, IC1.5 (VCC), ITSYBITSY_M4_EXPRESS.3V3 (+3V3), ITSYBITSY_M4_EXPRESS.3V3_2 (+3V3), J1.3, J2.3, J3.3, J4.3, J5.3, J6.3, J7.3, J8.3, J9.3, J10.3, J11.3, J12.3, R5.2, R6.1, R7.1, U1.2 (3V3)
+5V: ITSYBITSY_M4_EXPRESS.VHI, ITSYBITSY_M4_EXPRESS.VHI_2 (VHI), JP2.1
A0: ITSYBITSY_M4_EXPRESS.A0, ITSYBITSY_M4_EXPRESS.A0_2 (A0), J1.1
A1: ITSYBITSY_M4_EXPRESS.A1, ITSYBITSY_M4_EXPRESS.A1_2 (A1), J1.2
A2: ITSYBITSY_M4_EXPRESS.A2, ITSYBITSY_M4_EXPRESS.A2_2 (A2), J2.1
A3: ITSYBITSY_M4_EXPRESS.A3, ITSYBITSY_M4_EXPRESS.A3_3 (A3), J2.2
A4: ITSYBITSY_M4_EXPRESS.A4, ITSYBITSY_M4_EXPRESS.A4_2 (A4), J3.1
A5: ITSYBITSY_M4_EXPRESS.A5, ITSYBITSY_M4_EXPRESS.A5_2 (A5), J3.2
CHG: LED1.C, R1.1
D0: ITSYBITSY_M4_EXPRESS.RX_D0, ITSYBITSY_M4_EXPRESS.RX_D0_2 (RX_D0), J12.1, SJ5.2
D1: ITSYBITSY_M4_EXPRESS.TX_D1, ITSYBITSY_M4_EXPRESS.TX_D1_2 (TX_D1), J12.2, SJ6.2
D2: ITSYBITSY_M4_EXPRESS.D2, ITSYBITSY_M4_EXPRESS.D2_2 (D2), J11.1
D3: ITSYBITSY_M4_EXPRESS.D3, ITSYBITSY_M4_EXPRESS.D3_2 (D3), J10.1, J11.2
D4: ITSYBITSY_M4_EXPRESS.D4, ITSYBITSY_M4_EXPRESS.D4_2 (D4), J9.1, J10.2
D5_5V: ITSYBITSY_M4_EXPRESS.D5_5V, ITSYBITSY_M4_EXPRESS.D5_5V_2 (D5_5V), JP2.2
D7: ITSYBITSY_M4_EXPRESS.D7, ITSYBITSY_M4_EXPRESS.D7_2 (D7), J8.1, J9.2
D9: ITSYBITSY_M4_EXPRESS.D9, ITSYBITSY_M4_EXPRESS.D9_2 (D9), J7.1, J8.2
D10: ITSYBITSY_M4_EXPRESS.D10, ITSYBITSY_M4_EXPRESS.D10_2 (D10), J7.2, SJ7.2
D11: ITSYBITSY_M4_EXPRESS.D11, SJ_D11.2
D11_NC: ITSYBITSY_M4_EXPRESS.D11_NC (11_NC), SJ_D11.3
D12: ITSYBITSY_M4_EXPRESS.D12, SJ_D12.2
D12_NC: ITSYBITSY_M4_EXPRESS.D12_NC (12_NC), SJ_D12.3
D13: ITSYBITSY_M4_EXPRESS.D13, SJ_D13.2
D13_NC: ITSYBITSY_M4_EXPRESS.D13_NC (13_NC), SJ_D13.3
EN: ITSYBITSY_M4_EXPRESS.EN, ITSYBITSY_M4_EXPRESS.EN_2 (EN), JP1.2
ESP_BUSY: SJ_D11.1, U1.9 (IO33)
ESP_CS: IC1.1 (!OE), R5.1, SJ_D13.1, U1.29 (IO5)
ESP_GPIO: SJ7.1, U1.25 (IO0)
ESP_LED_B: LED2.6 (A_BLUE), U1.12 (IO27)
ESP_LED_G: LED2.5 (A_GREEN), U1.10 (IO25)
ESP_LED_R: LED2.4 (A_RED), U1.11 (IO26)
ESP_MISO: IC1.2 (A), U1.37 (IO23)
ESP_RST: R4.1, SJ_D12.1, U1.3 (EN)
ESP_RX: SJ6.1, U1.34 (TXD0)
ESP_TX: SJ5.1, U1.35 (RXD0)
GND: C1.2, C2.2, C3.2, C4.2, C5.2, C6.2, CN2.1, IC1.3 (GND), ITSYBITSY_M4_EXPRESS.GND, ITSYBITSY_M4_EXPRESS.GND_2 (GND), J1.4, J2.4, J3.4, J4.4, J5.4, J6.4, J7.4, J8.4, J9.4, J10.4, J11.4, J12.4, JP1.1, JP2.3, R2.1, R3.1, R4.2, RN1.5 (R4_2), RN1.6 (R3_2), RN1.7 (R2_2), RN1.8 (R1_2), U1.1 (GND), U1.15 (GND), U1.38 (GND), U1.GND, U3.2 (VSS)
MISO: IC1.4 (Y), ITSYBITSY_M4_EXPRESS.MISO, ITSYBITSY_M4_EXPRESS.MISO_2 (MISO)
MOSI: ITSYBITSY_M4_EXPRESS.MOSI, ITSYBITSY_M4_EXPRESS.MOSI_2 (MOSI), U1.13 (IO14)
unnamed: LED2.2 (K_GREEN), RN1.3 (R3_1)
unnamed: LED2.1 (K_BLUE), RN1.4 (R4_1)
unnamed: LED2.3 (K_RED), RN1.2 (R2_1)
unnamed: ITSYBITSY_M4_EXPRESS.AREF, ITSYBITSY_M4_EXPRESS.AREF_2 (AREF)
unnamed: ITSYBITSY_M4_EXPRESS.SWDIO, ITSYBITSY_M4_EXPRESS.SWDIO_2 (SWDIO)
unnamed: ITSYBITSY_M4_EXPRESS.SWCLK, ITSYBITSY_M4_EXPRESS.SWCLK_2 (SWCLK)
RST: ITSYBITSY_M4_EXPRESS.RST (RESET), ITSYBITSY_M4_EXPRESS.RST_2 (RESET)
SCK: ITSYBITSY_M4_EXPRESS.SCK, ITSYBITSY_M4_EXPRESS.SCK_2 (SCK), U1.30 (IO18)
SCL: ITSYBITSY_M4_EXPRESS.SCL, ITSYBITSY_M4_EXPRESS.SCL_2 (SCL), J4.1, J5.1, J6.1, R6.2
SDA: ITSYBITSY_M4_EXPRESS.SDA, ITSYBITSY_M4_EXPRESS.SDA_2 (SDA), J4.2, J5.2, J6.2, R7.2
STAT: R1.2, U3.1 (STAT)
VBAT: C2.1, CN2.2, ITSYBITSY_M4_EXPRESS.VBAT, ITSYBITSY_M4_EXPRESS.VBAT_2 (VBAT), U3.3 (VBAT)
VBUS: C1.1, ITSYBITSY_M4_EXPRESS.VBUS, ITSYBITSY_M4_EXPRESS.VBUS_2 (VBUS), LED1.A, U3.4 (VIN)

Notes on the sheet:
10K = 100mA
2.0K = 500mA
D0/D1
FILTERING
CHARGING
PERIPHERALS
GROVE HEADERS
ITSYBITSY M4 EXPRESS
ESP32 MODULE
RGB LED (ESP32)
MISO Tri-state
Power Enable
D5 5V (Neopixel)
Adriaan Bernstein
I²C Pullups

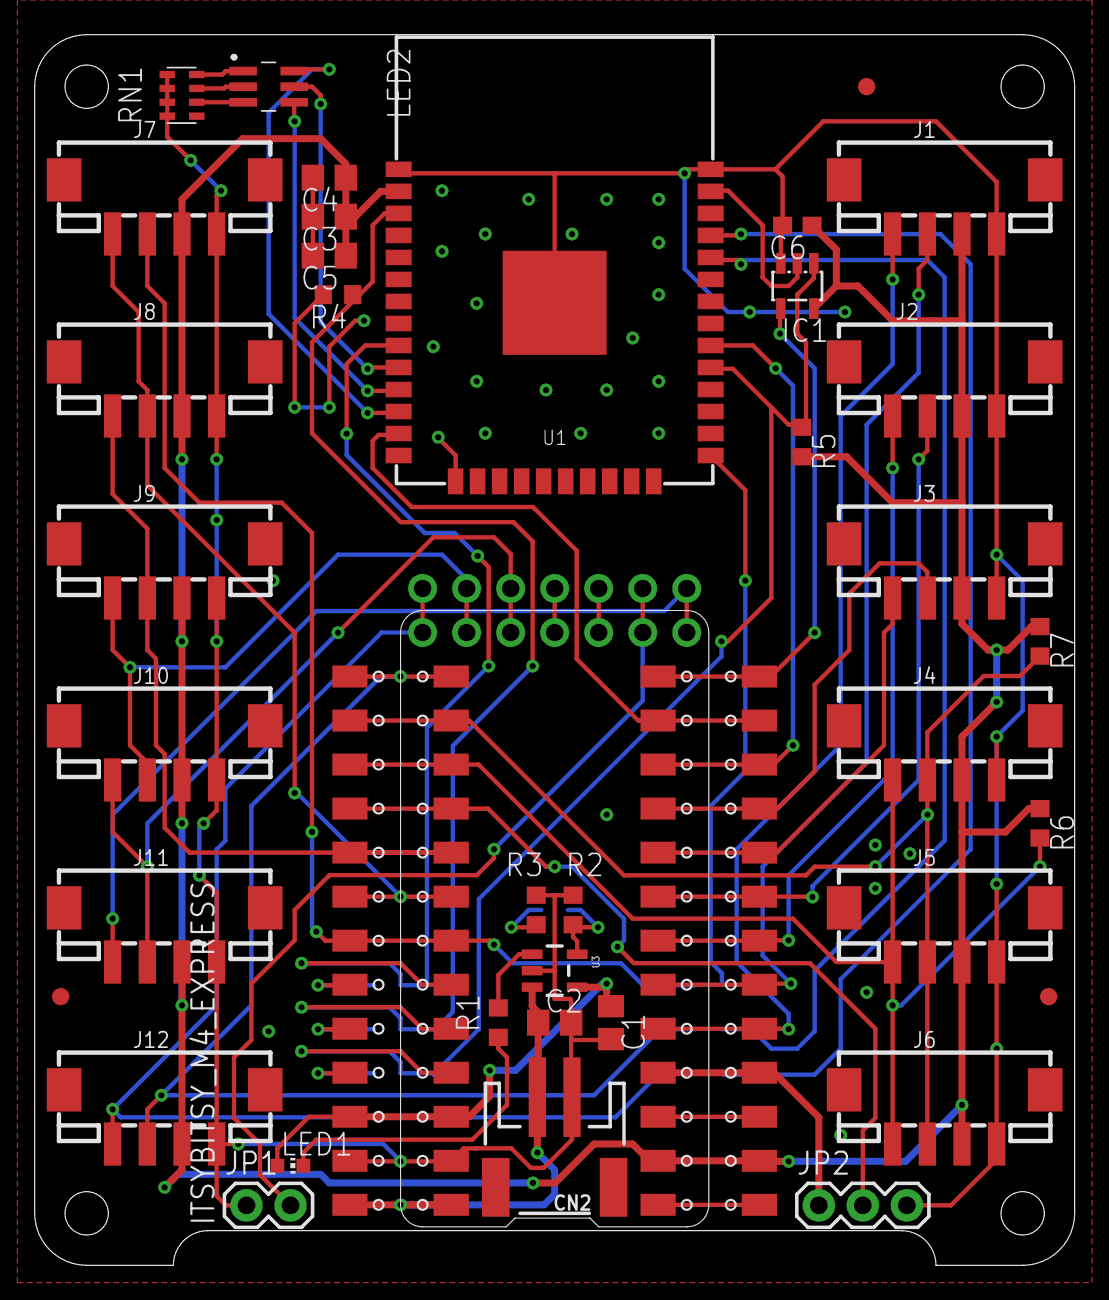
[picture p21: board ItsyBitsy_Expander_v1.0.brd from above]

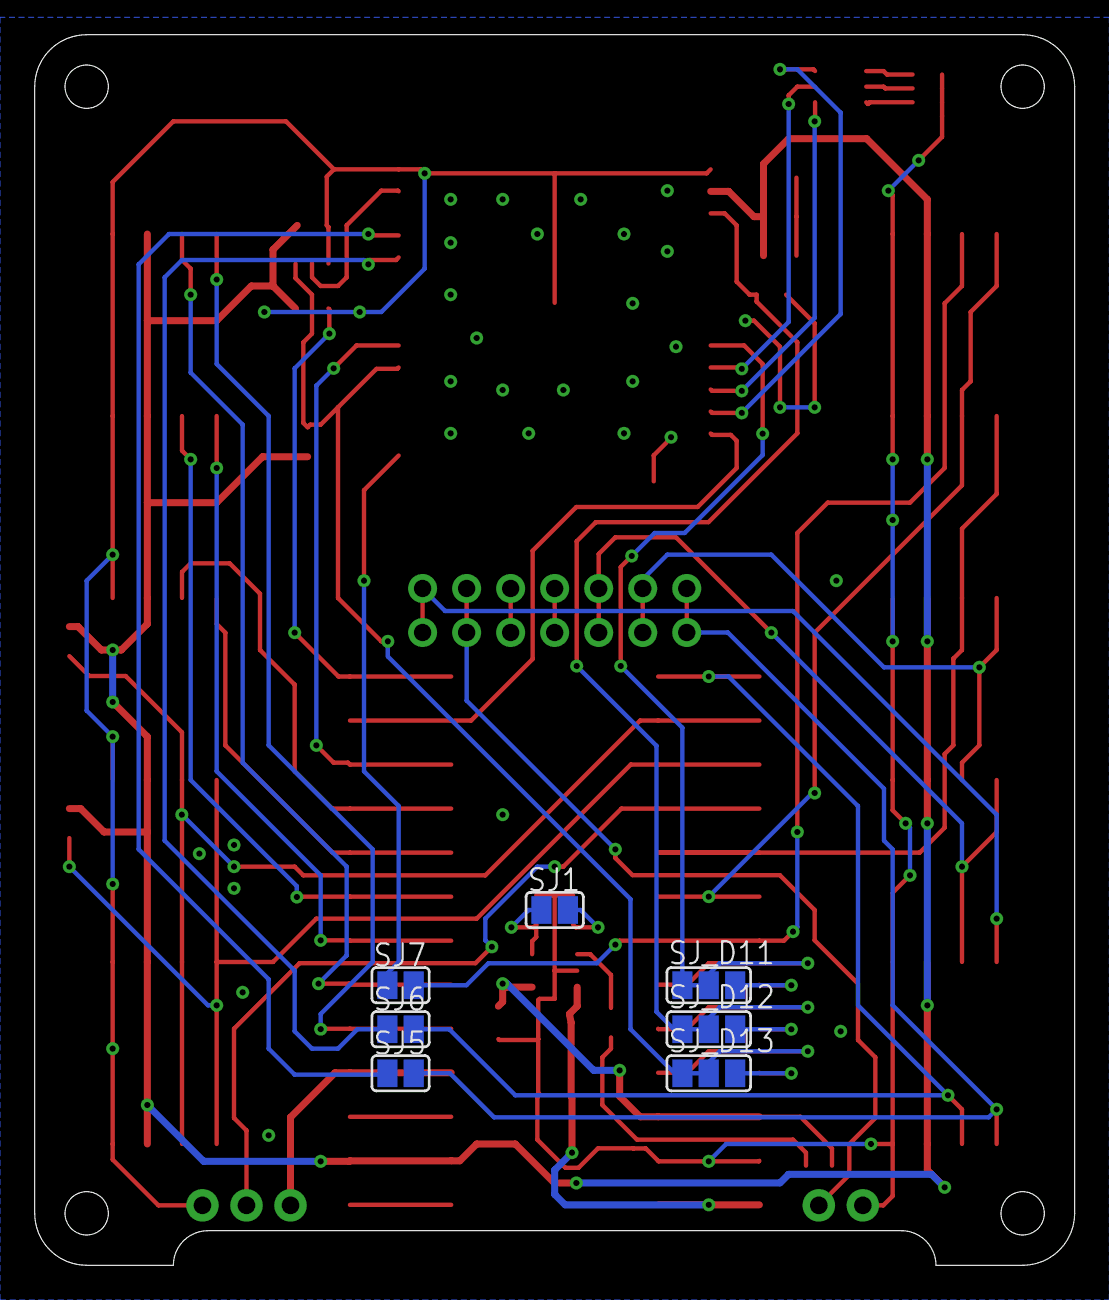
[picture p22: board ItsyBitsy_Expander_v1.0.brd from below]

Board: 2 copper layers, 60.0 x 71.0 mm, 45 parts (7 on the bottom side), 53 nets.

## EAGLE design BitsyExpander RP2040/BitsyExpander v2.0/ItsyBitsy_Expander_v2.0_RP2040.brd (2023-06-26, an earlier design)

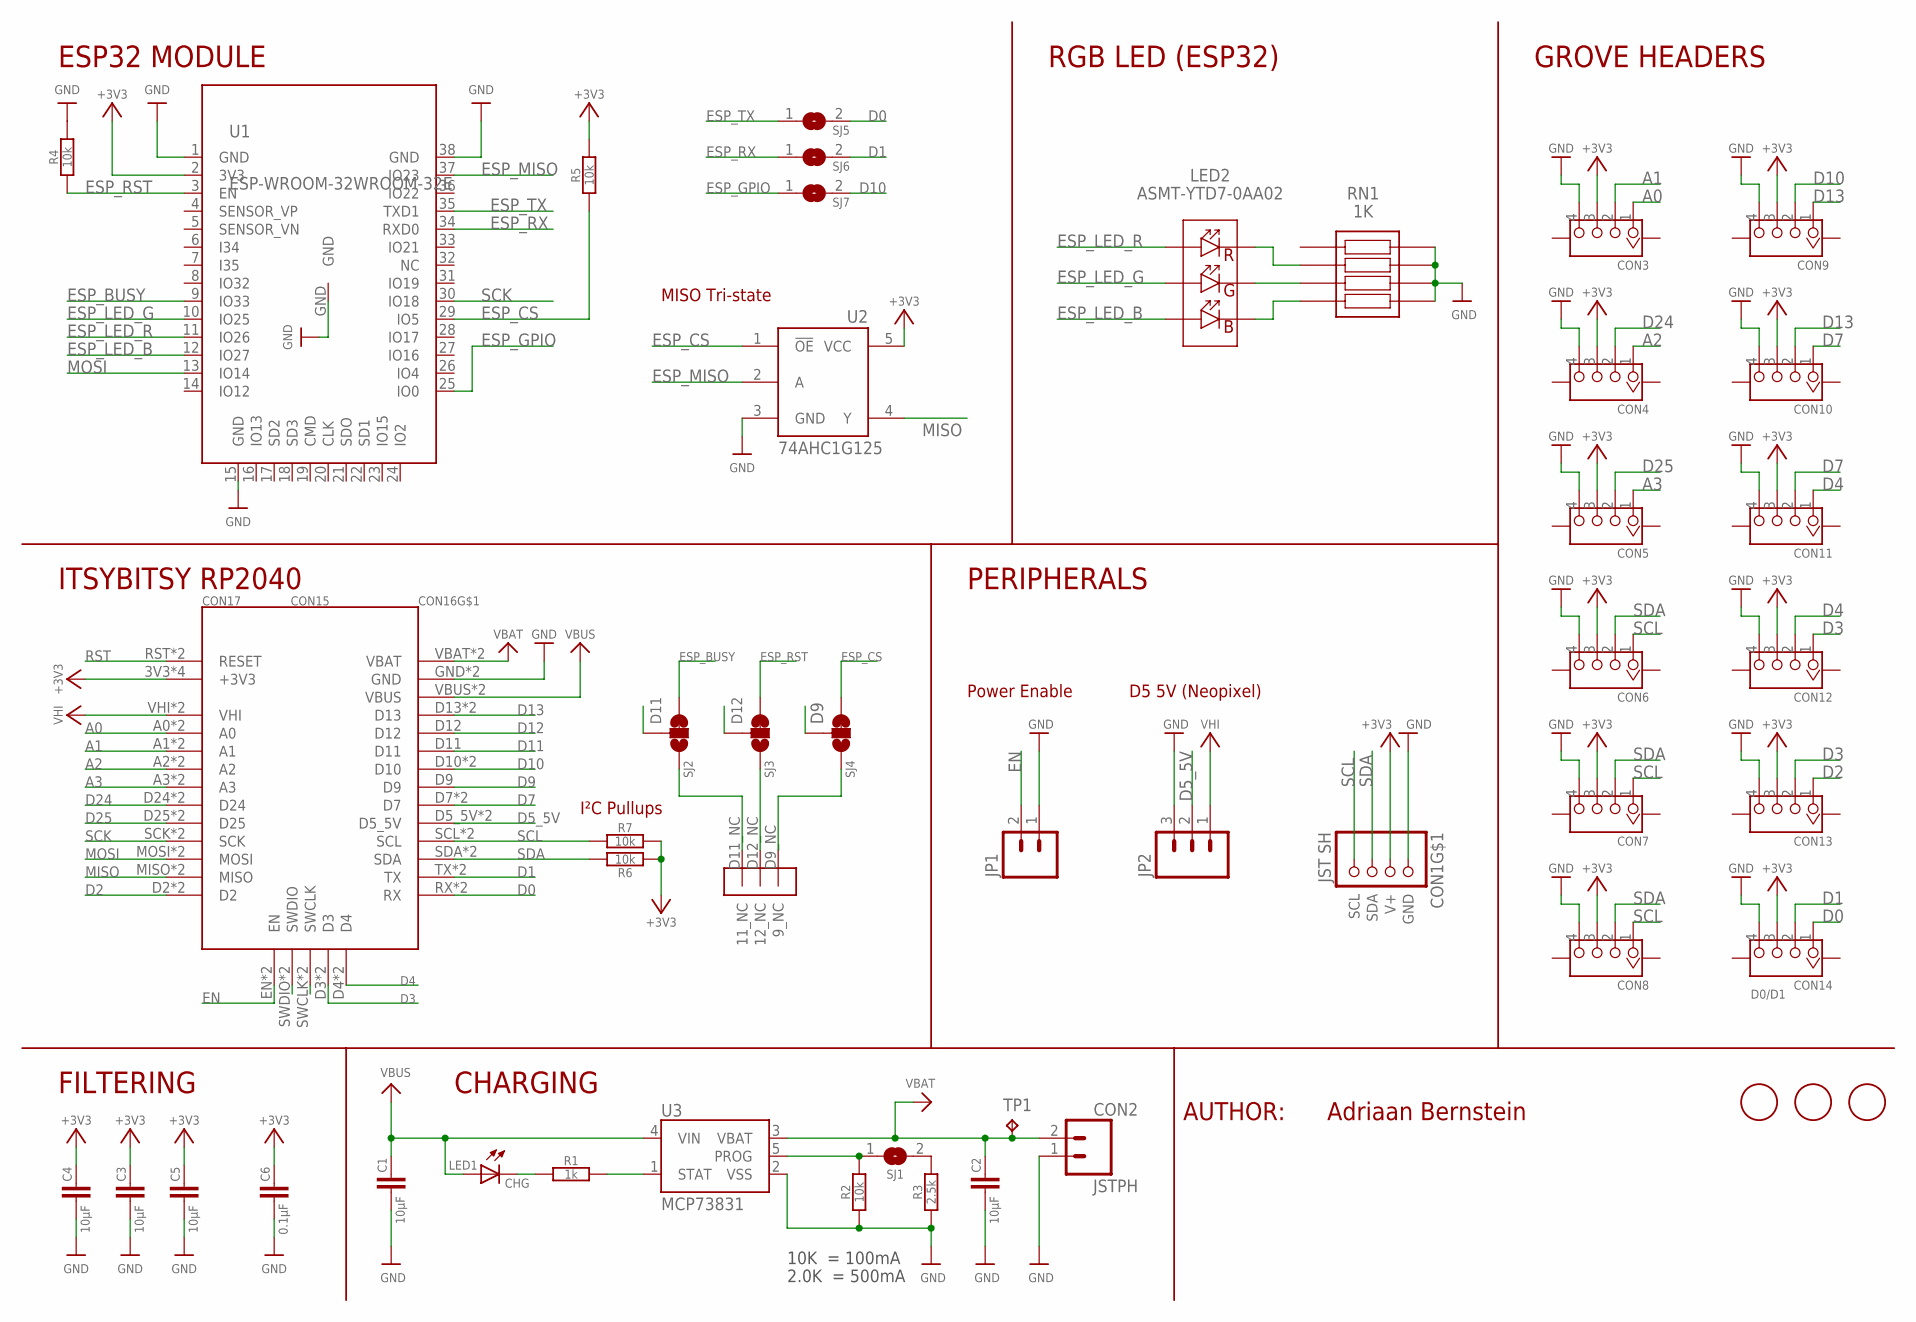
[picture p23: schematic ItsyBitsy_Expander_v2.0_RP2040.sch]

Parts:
C1, C2, C3, C4, C5: 10µF; C0805
C6: 0.1µF; C0805
CON1: JST SH; JST_SH4
CON2: JSTPH; JST-2-SMD
CON3, CON4, CON5, CON6, CON7, CON8, CON9, CON10, CON11, CON12, CON13, CON14: H4P-SMD-2.0; HW4-PTH-2.0
CON15: ITSYBITSY_RP2040_EDGEDEBUG; ITSYBITSY_RP2040_PTH_EDGEDEBUG
CON16: ITSYBITSY_RP2040_EDGEGND; ITSYBITSY_RP2040_SMD_EDGEGND
CON17: ITSYBITSY_RP2040_EDGEPWR; ITSYBITSY_RP2040_SMD_EDGEPWR
FD1, FD2, FD3: FIDUCIAL; FIDUCIAL_1MM
JP1: M02PTH; 1X02
JP2: M03PTH; 1X03
LED1: CHG; CHIP-LED0603
LED2: ASMT-YTD7-0AA02; ASMTYTD70AA02
R1: 1k; R0603
R2, R4, R5, R6, R7: 10k; R0603
R3: 2.5k; R0603
RN1: 1K; CAY1647R0F4LF
SJ1, SJ5, SJ6, SJ7: SJ
SJ_D11: SJ2; SJ_2WAY_CLOSED
SJ_D12: SJ3; SJ_2WAY_CLOSED
SJ_D13: SJ4; SJ_2WAY_CLOSED
TP1: TPB1,27; B1,27
U1: ESP-WROOM-32WROOM-32E; ESP-WROOM-32E
U2: 74AHC1G125; SOT23-5L
U3: MCP73831; SOT23-5

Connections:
2.5K: R3.2, SJ1.2
10K: R2.2, SJ1.1, U3.5 (PROG)
+3V3: C3.1, C4.1, C5.1, C6.1, CON1.2 (V+), CON3.3, CON4.3, CON5.3, CON6.3, CON7.3, CON8.3, CON9.3, CON10.3, CON11.3, CON12.3, CON13.3, CON14.3, CON17.3V3 (+3V3), CON17.3V3_2 (+3V3), CON17.3V3_3 (+3V3), CON17.3V3_4 (+3V3), R5.2, R6.1, R7.1, U1.2 (3V3), U2.5 (VCC)
+5V: CON17.VHI, CON17.VHI_2 (VHI), JP2.1
A0: CON3.1, CON17.A0, CON17.A0_2 (A0)
A1: CON3.2, CON17.A1, CON17.A1_2 (A1)
A2: CON4.1, CON17.A2, CON17.A2_2 (A2)
A3: CON5.1, CON17.A3, CON17.A3_2 (A3)
CHG: LED1.C, R1.1
D0: CON14.1, CON15.RX, CON15.RX_2 (RX), SJ5.2
D1: CON14.2, CON16.TX, CON16.TX_2 (TX), SJ6.2
D2: CON13.1, CON15.D2, CON15.D2_2 (D2)
D3: CON12.1, CON13.2, CON15.D3, CON15.D3_2 (D3)
D4: CON11.1, CON12.2, CON15.D4, CON15.D4_2 (D4)
D5_5V: CON16.D5_5V, CON16.D5_5V_2 (D5_5V), JP2.2
D7: CON10.1, CON11.2, CON16.D7, CON16.D7_2 (D7)
D9: CON16.D9, SJ_D13.2
D9_NC: CON16.D9_NC (9_NC), SJ_D13.3
D10: CON9.2, CON16.D10, CON16.D10_2 (D10), SJ7.2
D11: CON16.D11, SJ_D11.2
D11_NC: CON16.D11_NC (11_NC), SJ_D11.3
D12: CON16.D12, SJ_D12.2
D12_NC: CON16.D12_NC (12_NC), SJ_D12.3
D13: CON9.1, CON10.2, CON16.D13, CON16.D13_2 (D13)
D24: CON4.2, CON17.D24, CON17.D24_2 (D24)
D25: CON5.2, CON17.D25, CON17.D25_2 (D25)
EN: CON15.EN, CON15.EN_2 (EN), JP1.2
ESP_BUSY: SJ_D11.1, U1.9 (IO33)
ESP_CS: R5.1, SJ_D13.1, U1.29 (IO5), U2.1 (!OE)
ESP_GPIO: SJ7.1, U1.25 (IO0)
ESP_LED_B: LED2.6 (A_BLUE), U1.12 (IO27)
ESP_LED_G: LED2.5 (A_GREEN), U1.10 (IO25)
ESP_LED_R: LED2.4 (A_RED), U1.11 (IO26)
ESP_MISO: U1.37 (IO23), U2.2 (A)
ESP_RST: R4.1, SJ_D12.1, U1.3 (EN)
ESP_RX: SJ6.1, U1.34 (RXD0)
ESP_TX: SJ5.1, U1.35 (TXD1)
GND: C1.2, C2.2, C3.2, C4.2, C5.2, C6.2, CON1.1 (GND), CON2.1, CON3.4, CON4.4, CON5.4, CON6.4, CON7.4, CON8.4, CON9.4, CON10.4, CON11.4, CON12.4, CON13.4, CON14.4, CON16.GND, CON16.GND_2 (GND), JP1.1, JP2.3, R2.1, R3.1, R4.2, RN1.5 (R4_2), RN1.6 (R3_2), RN1.7 (R2_2), RN1.8 (R1_2), U1.1 (GND), U1.15 (GND), U1.38 (GND), U1.GND, U2.3 (GND), U3.2 (VSS)
MISO: CON17.MISO, CON17.MISO_2 (MISO), U2.4 (Y)
MOSI: CON17.MOSI, CON17.MOSI_2 (MOSI), U1.13 (IO14)
unnamed: LED2.2 (K_GREEN), RN1.3 (R3_1)
unnamed: LED2.1 (K_BLUE), RN1.4 (R4_1)
unnamed: LED2.3 (K_RED), RN1.2 (R2_1)
unnamed: CON15.SWDIO, CON15.SWDIO_2 (SWDIO)
unnamed: CON15.SWCLK, CON15.SWCLK_2 (SWCLK)
RST: CON17.RST (RESET), CON17.RST_2 (RESET)
SCK: CON17.SCK, CON17.SCK_2 (SCK), U1.30 (IO18)
SCL: CON1.4 (SCL), CON6.1, CON7.1, CON8.1, CON16.SCL, CON16.SCL_2 (SCL), R7.2
SDA: CON1.3 (SDA), CON6.2, CON7.2, CON8.2, CON16.SDA, CON16.SDA_2 (SDA), R6.2
STAT: R1.2, U3.1 (STAT)
VBAT: C2.1, CON2.2, CON16.VBAT, CON16.VBAT_2 (VBAT), TP1.TP, U3.3 (VBAT)
VBUS: C1.1, CON16.VBUS, CON16.VBUS_2 (VBUS), LED1.A, U3.4 (VIN)

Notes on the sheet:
10K = 100mA
2.0K = 500mA
D0/D1
FILTERING
CHARGING
PERIPHERALS
GROVE HEADERS
ITSYBITSY RP2040
ESP32 MODULE
RGB LED (ESP32)
MISO Tri-state
Power Enable
D5 5V (Neopixel)
I²C Pullups
AUTHOR:
Adriaan Bernstein

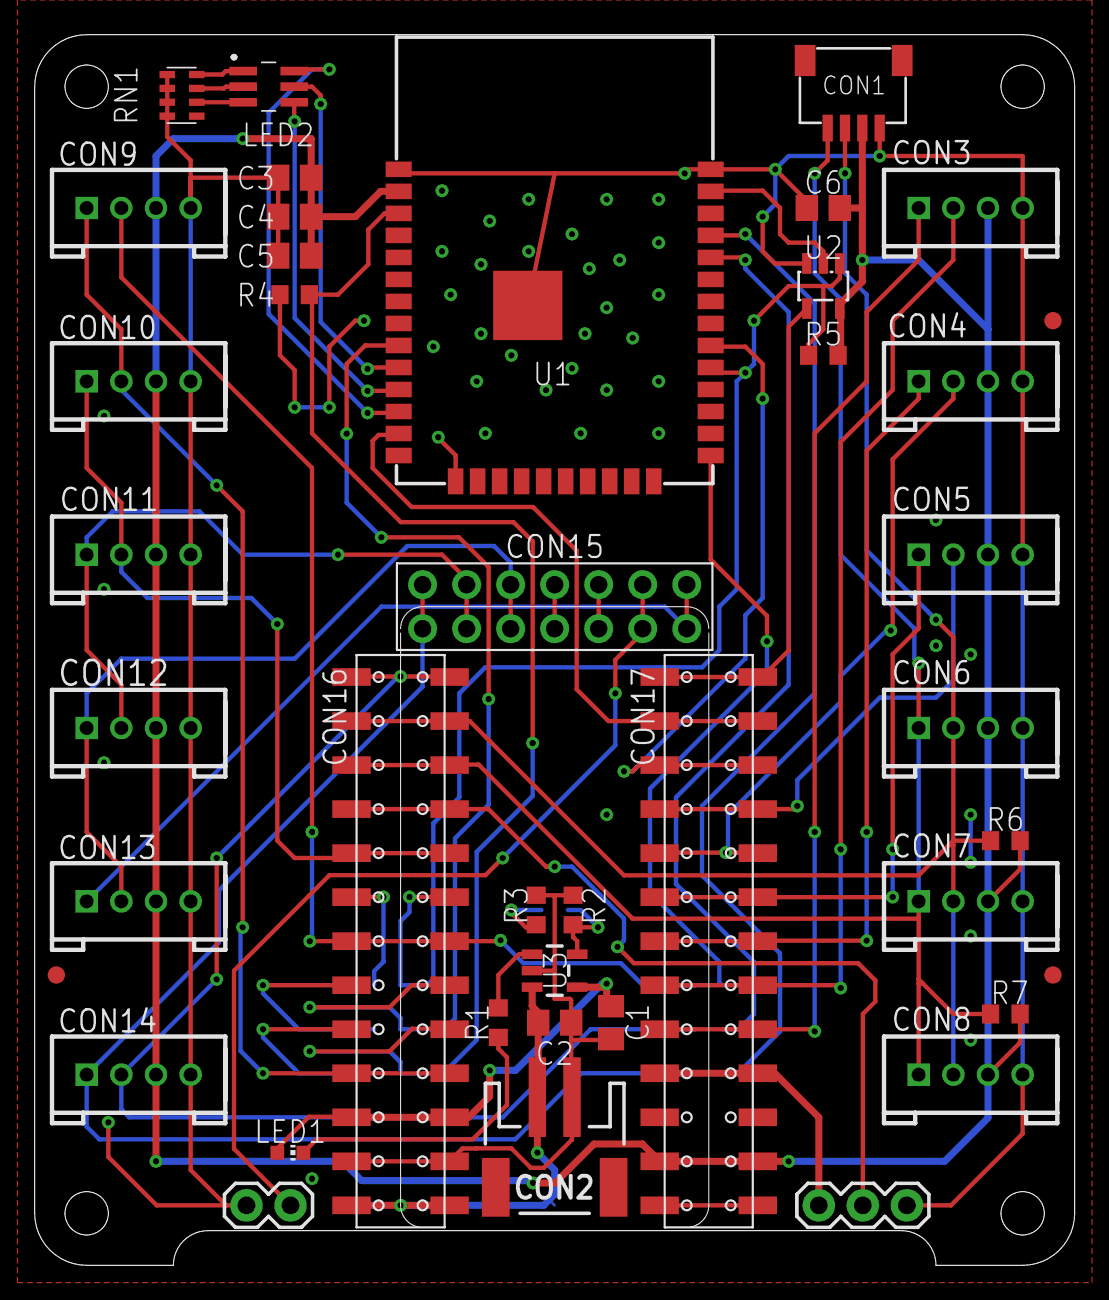
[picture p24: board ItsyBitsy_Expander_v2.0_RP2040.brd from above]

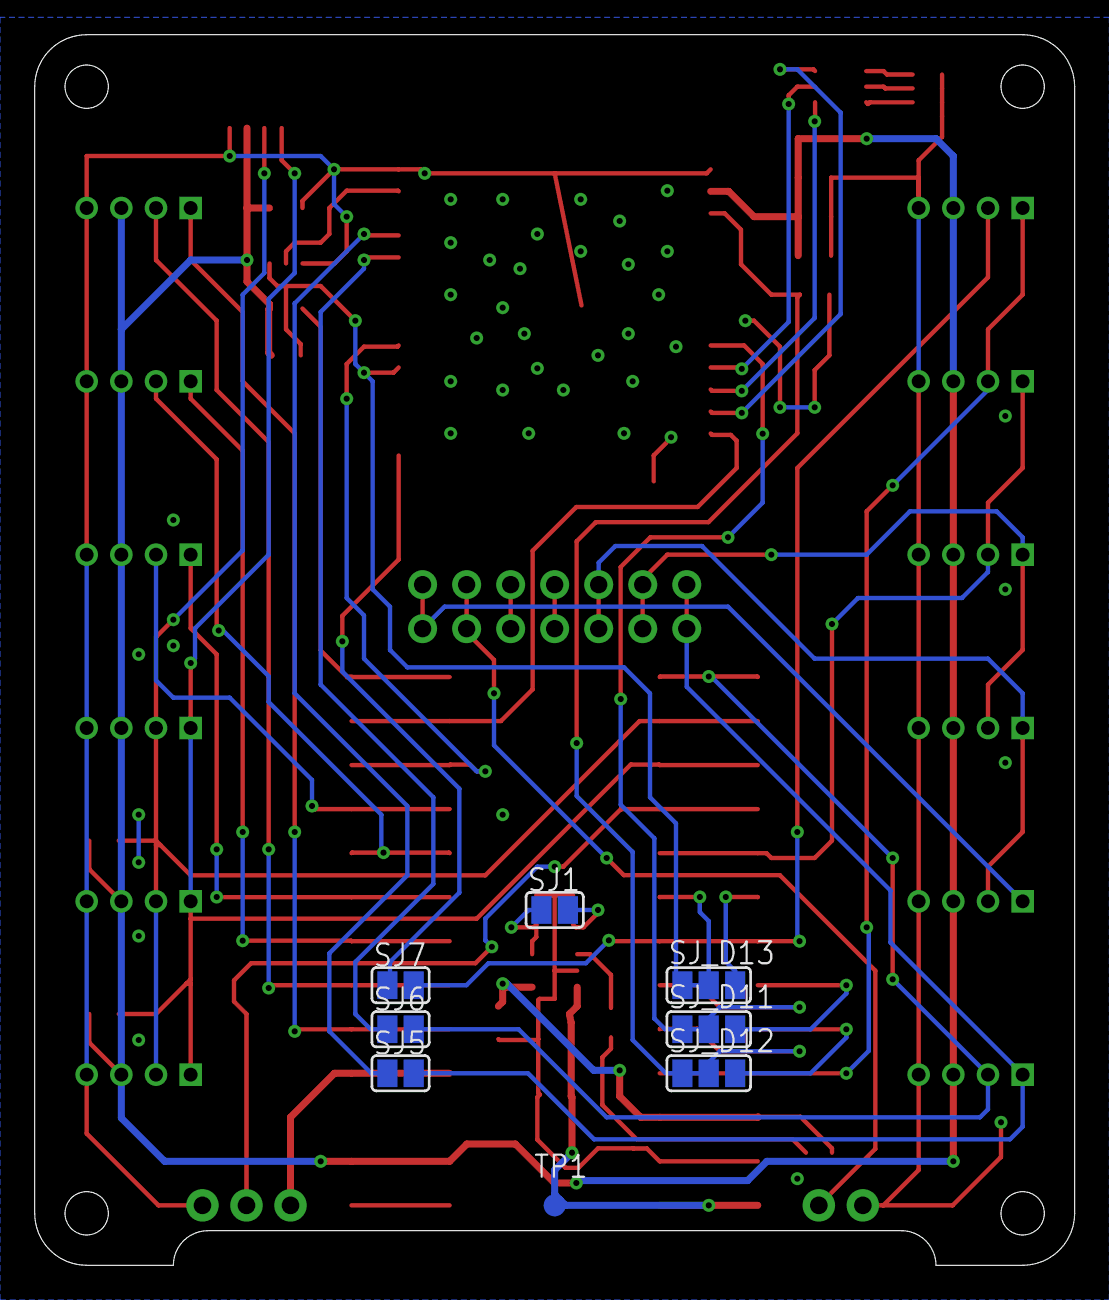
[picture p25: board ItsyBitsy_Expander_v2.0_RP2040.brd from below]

Board: 2 copper layers, 60.0 x 71.0 mm, 49 parts (8 on the bottom side), 52 nets.

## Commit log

2020-11-16 V1.0 eagle files and assets
    Eagle files and assets
    [BOM.xlsx, ItsyBitsy_Expander_v1.0.brd, ItsyBitsy_Expander_v1.0.sch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]
2020-11-25 Fix bug in ESP32 footprint
    Flip RX and TX pads
    [ItsyBitsy_Expander_v1.0.brd, ItsyBitsy_Expander_v1.0.sch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]
2020-12-02 Fix I²C footprint
    [ItsyBitsy_Expander_v1.0.brd, ItsyBitsy_Expander_v1.0.sch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]
2020-12-02 Upload V1.1
    * Use through-hole headers
    * Change CS pin for ESP32 coprocessor
    * Fix bugs in previous version (Serial breakout pads for ESP32, I²C header pinout)
    [BOM.xlsx, ItsyBitsy_Expander_v1.0.brd, ItsyBitsy_Expander_v1.0.sch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]
2020-12-02 Update readme, file cleanup
    [ItsyBitsy_Expander_v1.0.brd, ItsyBitsy_Expander_v1.0.sch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]
2021-11-08 Add ENIG PCB Previews
    Add ENIG PCB Previews for consistency
2021-11-08 Update README.md
    Update PCB Preview for consistency
2023-06-14 Restructuring and Cleanup
    [BOM RP2040 Expander.xlsx, BOM.xlsx, ItsyBitsy_Expander_v1.0.brd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]
2023-06-14 Version 3.0
    [BitsyExpander_v3.0_BOM.xlsx, BitsyExpander_v3.0_M4.brd, BitsyExpander_v3.0_M4.sch]
2023-06-19 Version 3.0 Assets and updated Gerber fileswith custom silkscreen
    [silkscreen_bottom.gbr, silkscreen_top.gbr]
2023-06-22 Add rev2.1, fixes to RP2040 specific silkscreen
    [BOM RP2040 Expander.xlsx, ItsyBitsy_Expander_v2.1_RP2040.brd, ItsyBitsy_Expander_v2.1_RP2040.sch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]

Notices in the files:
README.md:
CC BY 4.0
